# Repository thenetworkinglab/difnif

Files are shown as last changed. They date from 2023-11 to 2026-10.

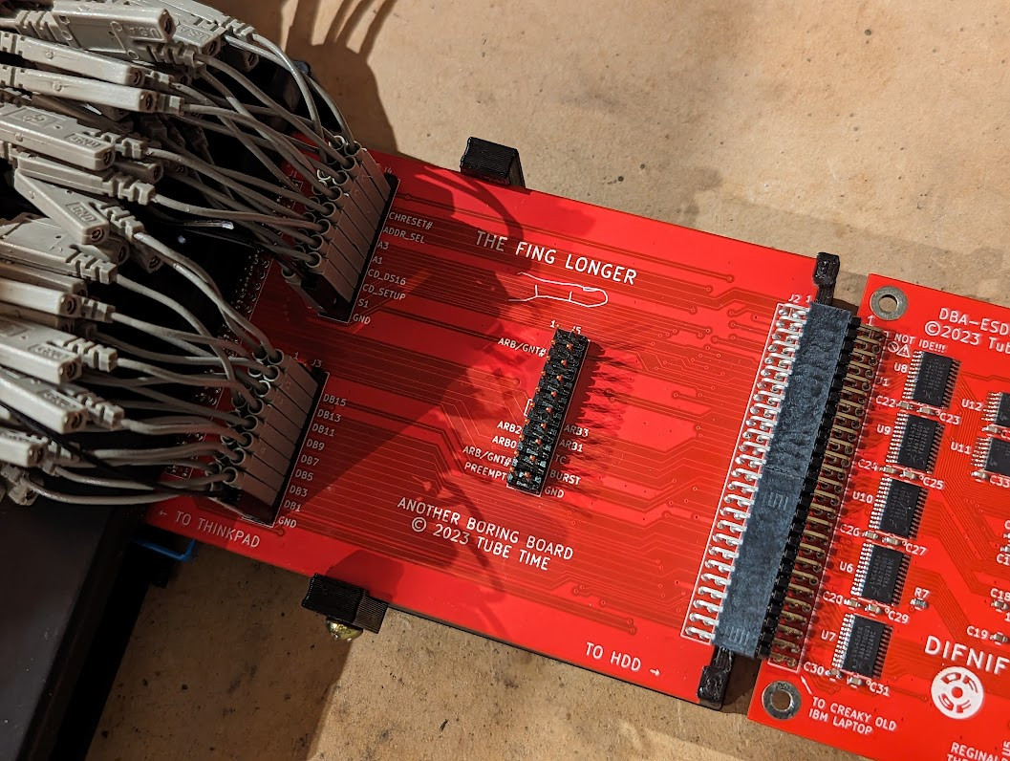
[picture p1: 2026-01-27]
photos/finglonger.jpg

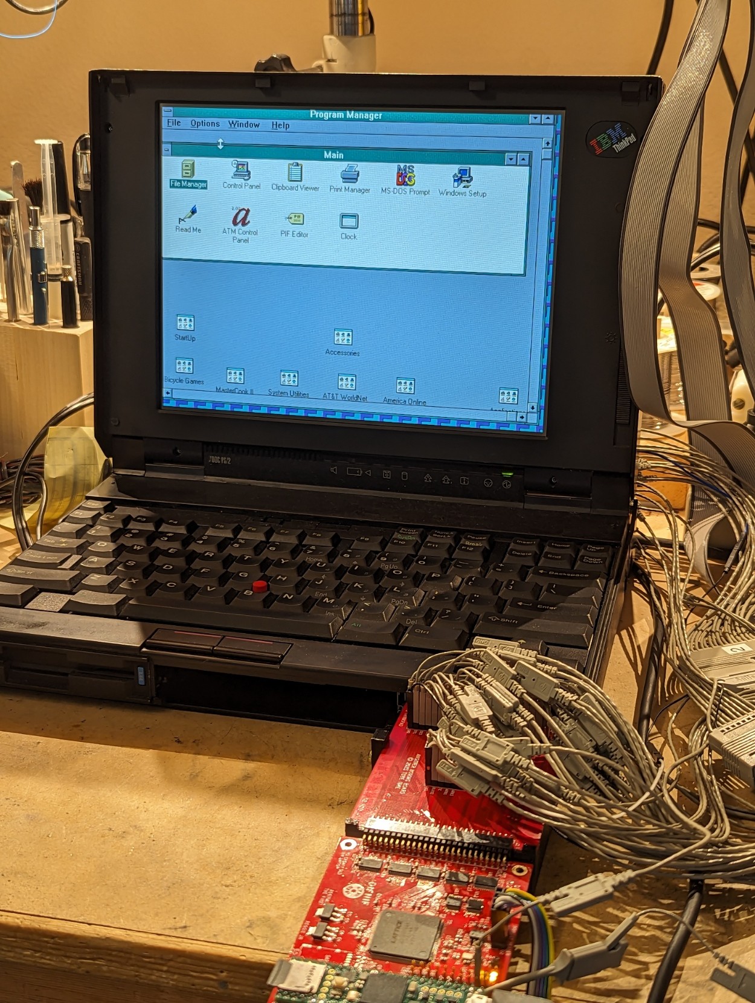
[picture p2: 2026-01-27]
photos/running.jpg

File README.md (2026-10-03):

# DifNif: DBA-ESDI Solid State Drive Emulator

DifNif is a drive emulator that replaces an IBM DBA-ESDI hard drive. 
It was designed by Eric Schlaepfer ([schlae/difnif](https://github.com/schlae/difnif)),
with the project's initial release intended to replace the hard drive in 
IBM ThinkPad 700C laptops, also including an alpha version of a PS/2 desktop 
form-factor emulator.  This fork is an attempt to complete 
the development of the 72-pin board for PS/2 desktops; the changes are 
listed in [docs/formfactor-review.md](docs/formfactor-review.md).

And before you ask: the name 'DifNif' comes from DF9F, 
the Micro Channel adapter ID that IBM's DBA-ESDI drives report.

**Status: alpha.** See "Status" below before building anything.

## Background

IBM PS/2 computers from the late 1980s and early 1990s typically used a
disk interface called DBA-ESDI (Direct Bus Attach - Enhanced
Small Device Interface). A DBA-ESDI drive has its controller integrated
with the drive electronics, and sits directly on the Micro Channel
bus, more like an IDE drive, but with its own register interface.

These drives are becoming rare because many have failed mechanically or
been damaged by leaking capacitors. MCA SCSI cards are an alternative on some
machines, but are getting expensive and difficult to find as well and 
aren't compatible with all PS/2s. Some PS/2s also need an IML (initial microcode load)
partition on their disk, and can only load it from a DBA-ESDI drive.

DifNif uses a Teensy 4.1 microcontroller and a Lattice iCE40 FPGA to implement the
DBA-ESDI interface, and stores the disk as an image file on an SD card. 

## Two boards, one design

The boards share the FPGA design (`verilog/`) and the Teensy firmware
(`difnift/`), and differ in how they connect to the computer.

| | ThinkPad board | PS/2 desktop board |
|---|---|---|
| Folder | [pcb_thinkpad](pcb_thinkpad/) | [pcb_formfactor](pcb_formfactor/) |
| Machines | ThinkPad 700C | PS/2 desktops that take a 72-pin DBA-ESDI drive, such as the 50Z, 55SX and 70 |
| Connector | 2 mm header, wired to the flex cable taken from a stock 700-series 2.5" drive | 72-pin (2 x 36) card edge, plugging straight into the drive socket |
| Carrier | [mech/df9f_carrier.STL](mech/df9f_carrier.STL) | [mech/difnif_PS2_drive_sled.STL](mech/difnif_PS2_drive_sled.STL), replacing the IBM drive sled |
| FPGA build | `make` | `make BOARD=ps2` |

There are also debugging aids:

- [pcb_finglonger](pcb_finglonger/), the "Fing Longer", for the ThinkPad board.
  It fits a 3D-printed sled ([mech/finglong.STL](mech/finglong.STL)) held by two
  clips ([mech/2finglong.STL](mech/2finglong.STL)). One acts as an extender
  that brings the connector forward, and a second as a breakout for logic
  analyzer probes on the bus lines.
- For the 72-pin board, a card in a spare Micro Channel slot gives access to
  the bus signals; Eric used a spare
  [Snark Barker MCA](https://github.com/schlae/snark-barker-mca).

## Status

- **ThinkPad board:** Eric's board works in a ThinkPad 700C,
  running Windows 3.1. The FPGA design has since been changed in this fork (see
  [docs/formfactor-review.md](docs/formfactor-review.md)), and those changes
  have **not** been tested on a ThinkPad. Eric's original files are on the
  `main` branch.
- **PS/2 desktop board, Rev P1** (Eric's): register communication didn't work
  reliably in a 50Z.
- **PS/2 desktop board, Rev P2** (this fork): fixes the problems found in a
  review of Rev P1, including a floating reset input that is the likely cause
  of the 50Z problem. The fixes have been checked in simulation against IBM's
  bus timing, but **Rev P2 has not yet been built or tested on real hardware.**
- Both boards' original design powers the 74LVC4245A level shifters the wrong
  way round, putting 5V on a supply pin rated for 4.6V at most. Rev P2 uses
  the TI SN74LVC8T245 instead, which accepts 5V on either side and fits the
  same footprint. The same swap should work on the ThinkPad board but hasn't
  been tried.
- Known bugs: writes occasionally produce a sector shifted by one byte; the
  cause hasn't been found.

[docs/formfactor-review.md](docs/formfactor-review.md) has the full list of
findings and changes, and [docs/verify-findings.md](docs/verify-findings.md)
explains how to check each one against Eric's original files and IBM's
documents.

**Data loss:** this is a hobby project with no formal testing. Keep backup
copies of all disk images.

## Building

This is an advanced project. It needs surface-mount soldering (or an
assembly service), two programmable devices to load, and probably debugging
with an oscilloscope and a logic analyzer.

### Boards

Each board folder has a `fab/` folder with Gerber and drill files. For the
Rev P2 PS/2 board, `pcb_formfactor/fab/` also has a parts list
(`DifNifFormFactor-RevP2-BOM.csv`) and a placement file
(`DifNifFormFactor-RevP2-positions.csv`) for an assembly service. The
ordering notes in [docs/formfactor-review.md](docs/formfactor-review.md)
cover board thickness, gold fingers and the bevelled edge.

The Teensy 4.1 plugs into two 24-pin female header strips (2.54 mm pitch, rows
15.24 mm apart). The SD card goes in the Teensy's own card slot.

### Teensy firmware

Load [difnift/difnift.ino](difnift/difnift.ino) with the Arduino IDE and
PJRC's Teensy board support, selecting Teensy 4.1.

For register loopback testing with DIFDIAG, comment out the two lines at the
start of `loop()` that call `esdiReset()` and `mainLoop()`. The serial monitor
then accepts the single-letter test commands listed at startup.

### FPGA

The FPGA design is built with the open-source iCE40 tools (yosys, nextpnr and
icestorm, for example from
[oss-cad-suite](https://github.com/YosysHQ/oss-cad-suite-build)). In
`verilog/`:

    make                  # ThinkPad board
    make BOARD=ps2        # PS/2 desktop board

The PS/2 build turns on the POS registers, so the card reports its `DF9F`
ID. Each build goes into its own folder, `build/thinkpad/` or `build/ps2/`.

The FPGA loads its program from an SPI flash chip on the board, which is
written through header J2 with an FTDI FT232H or FT2232H adapter and
`iceprog`:

    make prog BOARD=ps2

| J2 pin | Signal | FT232H pin |
|---|---|---|
| 1 | Flash chip select | AD4 |
| 2 | CDONE | AD6 |
| 3 | SCK | AD0 |
| 4 | CRESET | AD7 |
| 5 | Flash data out (CIPO) | AD2 |
| 6 | GND | GND |
| 7 | Flash data in (COPI) | AD1 |
| 8 | +3.3 V (board supply, leave unconnected) | |

The board must be powered while programming. The Teensy's USB connection can
power it on the bench.

The source files are:

- `difnif_top.v`: top level, wiring up the other modules.
- `mcabus.v`: the Micro Channel bus interface, with the ESDI registers, POS
  registers and DMA.
- `teensy.v`: the register interface that lets the Teensy, in its own clock
  domain, reach the ESDI mailbox registers and flags.

The self-checking bus simulation for the PS/2 board is `difnif72_t.v`, run with
`./run_sim72.sh` (needs Icarus Verilog).

## Drive images

The Teensy firmware uses a file called `disk0.img` in the root of the SD card.
Its size must be a whole number of megabytes, up to 1023 MB; for example, for
120 MB:

    dd if=/dev/zero of=disk0.img bs=1048576 count=120

Then use the machine's reference disk to create the IML and reference
partitions, and install DOS to partition and format the rest of the disk.

## DIFDIAG

[difdiag/DIFDIAG.CPP](difdiag/DIFDIAG.CPP) is a diagnostic utility for
DBA-ESDI drives that works directly with the drive hardware at a very low
level. Don't use it on drives containing data you care about, but it can help
with troubleshooting dead drives. It compiles with Borland C++ using the Large
memory model.

Menus:

- **Settings:** DMA configuration. Autoconfigure tries to get the DMA channel
  through a BIOS call, and failing that from the extended BIOS data area
  (EBDA). The channel can also be set by hand, or PIO mode chosen instead.
- **Mailbox tests:** not for real drives. With DifNif in loopback test mode
  (see "Teensy firmware"), runs millions of register cycles to look for timing
  problems.
- **Low level commands:** the lowest-level commands, which must be run in the
  sequence given by the flowcharts in the
  [ESDI spec](https://ardent-tool.com/docs/pdf/j_mcspec.pdf).
- **Drive information:** query commands; generally safe on real drives.
- **POST tests:** modelled on the drive tests run by the PS/2 BIOS.
- **Run diagnostics:** the DBA-ESDI interface's own low-level hardware
  diagnostic command.
- **Int13 tests:** destructive. Writes data through the BIOS int13 routines,
  reads it back and compares.
- **Read sector:** reads one or more sectors and shows them in hex.

## Reference documents

- [IBM DBA-ESDI reference](https://ardent-tool.com/docs/pdf/j_mcspec.pdf)
- [DBA-ESDI 72-pin connector pinout](https://ardent-tool.com/storage/DBA_ESDI.html)
- [IBM PS/2 Hardware Interface Technical Reference, Micro Channel chapter](https://ardent-tool.com/docs/pdf/ps2_50-60_techref_ch2_microchannel_architecture.pdf)

## License

Designed by Eric Schlaepfer; modified in this fork by thenetworkinglab (2026).
Licensed under the
[CERN Open Hardware Licence Version 2 - Strongly Reciprocal](https://ohwr.org/cern_ohl_s_v2.txt).

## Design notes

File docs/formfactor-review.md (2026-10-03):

# 72-pin (form factor) board: static review

Review of `pcb_formfactor/` (Rev P1) and the matching Verilog, done before
building any hardware. The goal is to get the 72-pin DifNif working in the
PS/2 55SX and 70, which use the same 2x36 DBA-ESDI edge connector as the 50Z.

Original design by Eric Schlaepfer ([schlae/difnif](https://github.com/schlae/difnif)),
CERN-OHL-S-2.0. This document and `tools/check_board.py` are additions in this fork.

## How to rerun

```
python3 tools/check_board.py
```

It exports the netlist with KiCad's `kicad-cli` and checks it against the
published connector pinout (`tools/dba_esdi_72pin.csv`), the FPGA pin file
(`verilog/difnif.pcf`) and the 74LVC4245 datasheet. It exits non-zero while
any ERROR remains, so it can gate a Rev P2 schematic.

KiCad's own ERC was also run. Almost everything it reports is noise: missing
libraries (Eric's custom libraries aren't in the repo), unused Teensy pins, and
the half-populated logic-analyzer header. It did **not** catch findings 1 or 2,
because the level-shifter pins are typed "bidirectional".

## Findings

| # | Severity | Finding | Affects |
|---|---|---|---|
| 1 | Critical | FPGA `chreset` input is floating | 72-pin only |
| 2 | High | 74LVC4245 supply rails are swapped (5 V on a 4.6 V abs-max pin) | Both boards |
| 3 | Resolved | `-ADL` not connected: not needed (IBM allows latching on `-CMD`; 17 ns hold margin) | 72-pin only |
| 4 | Medium | `-CD SFDBK` not driven (Verilog fixed; needs Rev P2 wiring) | 72-pin only |
| 5 | Low | Address decode ignores POS alternate address, answers at 0x3518-351F (fixed) | 72-pin only |
| 6 | Low | `addr_sel_l` is a `wire` assigned in an `always` block (fixed) | Verilog |
| 7 | Low | Only 6 debug signals reach the logic-analyzer header | Both boards |
| 8 | High | No key slot in the board outline | 72-pin only |
| 9 | High | Write data is captured on the falling edge of `-CMD`, where IBM guarantees 0 ns setup (fixed) | Both boards |
| 10 | High | Eric's default build hides the POS registers, including the `DF9F` adapter ID | Build setting |
| 11 | Low | Status register can change during a read cycle | Both boards |
| 12 | High | Card can bid for DMA again with a request already serviced (fixed) | Both boards |
| 13 | Note | Card relies on the planar re-arbitrating after every DMA transfer | Both boards |
| 14 | Low | The Teensy's "16-bit transfer" flag shows the width of the last bus cycle of any kind, not the last data transfer | Both boards |

### 1. FPGA `chreset` input is floating

Connector pin **B14 is `CHRESET`, active high** (IBM pinout). The schematic
names it `~{CHRESET}` and routes it through U8 channel 7 (pin 14 to pin 10) to
FPGA pin 52 (`chreset_l`), which no logic uses.

The logic uses `chreset` on FPGA pin 76. That comes from U8 pin 15
(`CHRESET_5V`), and **nothing is connected to U8 pin 15**. On the ThinkPad
board it's fed from connector pin 2.

`chreset` gates every bus access
([mcabus.v](../verilog/mcabus.v) `assign addressed = ... & ~chreset`), so
whether the card answers depends on a floating CMOS input. This matches
the README's "register communications don't work correctly".

- **Rev P1 rework:** bridge U8 pins 14 and 15 (adjacent pads). Pin 76 then
  sees the real CHRESET. No firmware change is needed.
- **Rev P2:** connect B14 to U8 pin 15 (`CHRESET_5V`). This frees U8 channel 7
  for `-ADL` (finding 3).

### 2. 74LVC4245 supply rails are swapped

All six transceivers (U6-U10, U14) are Nexperia 74LVC4245APW, per the Mouser
field. The datasheet says **pin 1 is VCC(A), the 5 V side (up to 5.5 V)**, and
**pins 23/24 are VCC(B), the 3 V side (abs max 4.6 V)**, with VCC(A) >= VCC(B).
Both boards do the opposite: pin 1 is at +3V3 and pins 23/24 are at +5V. The A
port faces the FPGA and the B port faces the bus. This was confirmed in the PCB
files as well as the schematics.

The logic still works, because each port follows its own supply. But VCC(B)
sits 0.4 V above its absolute maximum rating. The ThinkPad board works in
practice, so this probably isn't the 72-pin failure. Still, parts running
outside their ratings can behave marginally or degrade over time.

- **Fix (no layout change):** fit **TI SN74LVC8T245PW** instead. It has the same
  TSSOP-24 package and pinout: pin 1 VCCA, pin 2 DIR, pins 3-10 A, pins 14-21 B,
  pin 22 /OE, pins 23/24 VCCB. Both rails can be anywhere from 1.65 V to 5.5 V.
  DIR and /OE are referenced to VCCA (3.3 V here), which suits the FPGA driving
  DIR. The function table is the same (DIR low = B to A, high = A to B), so
  the Verilog doesn't change. This applies to both the 72-pin and ThinkPad boards.

### 3. `-ADL` not connected

On the ThinkPad connector, the system board decodes the address and hands the
drive `-ADDR_SEL` plus A0-A3. On the 72-pin connector the card gets A0-A15 raw,
and [difnif_top.v](../verilog/difnif_top.v) decodes A15-A4 without a latch. The
result is sampled on the falling edge of `-CMD`, and `-ADL` (pin A20) isn't
connected.

**Resolved: `-ADL` isn't needed.** Figure 2-34 guarantees that address and
status stay valid for at least 30 ns after `-CMD` falls (T9, T10), and note 2
explicitly allows latching on the leading edge of `-CMD` instead of `-ADL`. The
simulation passes with the address going invalid exactly at the 30 ns limit,
and the timing check below leaves 17 ns of hold margin inside the FPGA.

- **Rev P2 (optional):** A20 could still go to the spare U8 channel, freed by
  the finding 1 fix, as a debug aid. Nothing depends on it.

### 4. `-CD SFDBK` not driven

Pin B08 is `-CD SFDBK` (card selected feedback). The board leaves it open.
IBM Figure 2-34, note 1: "All slaves must drive -CD SFDBK whenever selected."
It has to come from the unlatched address decode (note 3).

- **Rev P2:** drive it through U12's spare fourth 74VHCT125 section: FPGA signal
  on the input (pin 12), /OE (pin 13) grounded, output (pin 11) to B08. That
  makes it push-pull, which is the driver type Micro Channel specifies for
  `-CD SFDBK`, the same as `-CD DS 16`. (An earlier version used the enable pin
  as an open-drain driver; it was swapped during layout, see "Rev P2 schematic
  changes".)

### 5. Address decode

`addr_sel_l <= ~(bus_a[15:4] == 12'h351)` matches 0x3510-351F. The ESDI ports
are 0x3510-3517 (primary) and 0x3518-351F (alternate, chosen by POS). As
written, the card also answers reads at the alternate address, driving `FFFF`
onto the bus and asserting `-CD DS16`. Decode A3 as well and select the base
from POS register 2 bit 1.

### 6. Verilog: `wire` assigned in `always`

`addr_sel_l` is declared `wire` in `difnif_top.v` but assigned inside
`always @(*)`. Standard Verilog rejects this and some tools refuse it. Use
`reg`, or better an `assign`, which the `-ADL` rewrite replaces anyway.

### 7. Debug visibility

The logic-analyzer header J4 only carries the six SD-card pins, which the FPGA
reuses as test outputs. For the first Rev P2 board, add test points or a second
header on `-ADL`, `-CMD`, `-S0`/`-S1`, `CHRESET`, the address decode, and
`-CD DS16`.

### 8. No key slot in the board outline

The IBM drive's edge connector has a key slot between pins 2 and 3, visible
on both rows of a WD-3158. Eric's `BUS_DBA_ESDI` footprint draws the slot, at
the right position (1.27 mm past pin 2), but only on the `Dwgs.User` layer. The
board outline and the fab Gerber (`DifNif-Edge_Cuts.gbr` in the RevP1 zip) are
a plain 98.8 x 93.0 mm rectangle with no slot. The 55SX's cable-end socket has a
key ridge, so Rev P1 won't go into a 55SX without a slot cut by hand. The Model
70's riser socket has no key, so Rev P1 fits there as it is.

Measured on a WD-3158: the slot is **11.7 mm deep** and about **1.0 mm wide**,
cut right up against the edges of fingers 2 and 3 with no copper margin. The
IBM fingers are about 1.5 mm wide, the same as Eric's 1.524 mm, so the slot
fills the roughly 1.0 mm gap between them. The key ridge in the 55SX
flat-flex cable socket measures about **0.7 mm** thick, and the cable is keyed
at both ends. The Model 70's riser socket is **not** keyed (checked on a real
machine): its chassis makes it practically impossible to fit a drive upside
down, whereas the 55SX's loose flex cable could be plugged in either way with
the machine apart. The slot is harmless in the Model 70.

- **Rev P2 (done):** a slot 1.0 mm wide and **8.7 mm** deep, centred between
  pins 2 and 3, with a rounded end, and fingers a2/a3/b2/b3 narrowed to 1.0 mm
  (centred) for 0.27 mm of copper-to-edge clearance. The slot doesn't need
  IBM's 11.7 mm: the drive goes only 7.5-7.8 mm into the 55SX cable socket
  (measured by fitting the socket on the WD-3158), so the key ridge can't
  reach further than that. 8.7 mm is the deepest slot that clears the existing
  traces fanning out from fingers A1/A2/B1/B2 (8.8 mm touches `A13`), leaving
  about 1 mm of margin. Check the board house's minimum routed slot width
  (often 1.0 mm) and copper-to-edge clearance.
- **Rev P1:** could be keyed by hand. A fine jeweller's saw (about 0.8 mm kerf)
  cutting down the 1.0 mm gap between fingers 2 and 3, about 8.5 mm deep,
  would clear the 0.7 mm ridge.

### 9. Write data captured at the falling edge of `-CMD`

[mcabus.v](../verilog/mcabus.v) stores host writes (CIFR, ATN, BCR, DREG and
POS registers) on `negedge cmd_l`. IBM Figure 2-34 only guarantees write data
**0 ns** before `-CMD` falls (T17), and 30 ns after `-CMD` *rises* (T18). With
data arriving at the limit, any data line whose path through the level shifter
is slower than the `-CMD` line's gets captured before the new value arrives.

The simulation reproduces this: at IBM's timing limits, host writes fail on 7
of 8 randomly chosen sets of level-shifter delays, on all three machines. Reads
are unaffected. Eric's measurements on his 50Z show about 50 ns of write setup,
which is why typical timing passes. How much setup the 55SX and Model 70 really
give is unknown.

This affects both boards and could contribute to the README's "sector written
is shifted by one byte" bug, though that isn't proven.

- **Verilog fix:** latch the address and status on the falling edge (as now),
  but store the write data on the rising edge of `-CMD`, where it is guaranteed
  valid for another 30 ns. The Teensy-facing "register full" flags have to move
  with it, so the Teensy never sees a flag before its data.

### 10. POS registers hidden in Eric's default build

`mcabus.v` defines `MCA_NO_POS` ("POS bypass", added January 2026). The card
is then always enabled but never answers setup cycles, so the host can't read
the `DF9F` adapter ID. The ThinkPad presumably doesn't need it. On the 72-pin
connector the drive has its own `-CD SETUP` line, and the 50Z/55SX/70 BIOS
probably reads the ID to find the drive. The define can now be overridden with
`-DMCA_USE_POS` without changing the default, and the simulation passes the POS
tests in that mode. Build the 72-pin board's FPGA program with
`make BOARD=ps2` in `verilog/`, which sets it (plain `make` builds the
ThinkPad version, POS bypassed, into a separate folder). Program it with
`make prog BOARD=ps2`.

### 11. Status register can change during a read

The basic status register is read live, not snapshotted when the cycle starts.
If a flag changes while `-CMD` is low (for example the Teensy emptying CIFR),
the data on the bus changes mid-cycle. IBM wants read data valid within 60 ns
of `-CMD` falling (T20). Each bit is either the old or the new value, so this is
usually harmless, but a snapshot at the start of the cycle would be cleaner.
The simulation reports these as SPEC notes, not failures.

### 12. DMA request dropped too late

The card asks for DMA while its data-register request flag (`flag_treq`) is
set. A DMA transfer clears that flag through the 50 MHz synchronizer, 40-60 ns
after the transfer's `-CMD` rises. IBM allows the next arbitration cycle to
start 30 ns after the end of a transfer (Figure 2-46, T41). The card decides
whether to compete when `ARB/-GNT` rises, so on a planar that re-arbitrates
that quickly, it competes again with a request that has already been serviced,
wins, and receives (or supplies) a word the Teensy isn't ready for.

The simulation reproduces it at IBM's limits: a whole 16-word DMA transfer went
through on a single request. At typical timing (arbitration 100 ns after the
transfer) it doesn't happen. How fast real 55SX and Model 70 planars
re-arbitrate is unknown. This may also be what Eric's "fix rare dma glitch"
commit was working around.

**Fixed:** `dma_requested` is now also gated by `treq_pending`, which rises the
moment a DREG or DMA cycle's `-CMD` rises and falls one clock after `flag_treq`
clears, so the request never glitches back on.

### 13. Dependence on re-arbitration after DMA

After winning arbitration, the card stays "DMA selected" for any I/O cycle
until `ARB/-GNT` next goes high (`dma_cycle` only updates on that edge). If a
planar handed the bus back to the CPU without an arbitration cycle, the card
would treat the CPU's next I/O cycles as DMA transfers. IBM's timing (T41) and
Eric's note about the real 50Z in `mcabus_t.v` indicate the planar does
re-arbitrate after each transfer, and the simulation models it that way. This
is worth confirming with a logic analyzer on real hardware.

### 14. "16-bit transfer" flag tracks every bus cycle

The FPGA gives the Teensy a flag (`t_treq_16`, flag register bit 9,
`FLAG_TRANSFER_16` in `difnift.ino`) meant to say whether the last data
register (DREG) transfer was 8 or 16 bits wide. [mcabus.v](../verilog/mcabus.v)
sets it from `-SBHE`, which is latched on the falling edge of `-CMD` in
**every** bus cycle, including other devices' cycles and the host's own status
polls. In simulation it read 0 after every transfer, even 16-bit ones, because
the host's 8-bit reads of the status register came in between.

The firmware never reads the flag; it treats every transfer as 16 bits. That's
fine as long as the host always moves sector data 16 bits at a time, which it
should, since the card asserts `-CD DS 16` for DREG and DMA cycles. If 8-bit
transfers ever need supporting, the FPGA should latch `-SBHE` only on DREG and
DMA cycles, and the firmware should check the flag.

### The "shifted by one byte" write bug (open)

Eric's README reports occasional sector writes that come out shifted by one
byte. The cause isn't known. Checked so far:

- **8-bit transfers: ruled out as the cause.** A temporary simulation had the
  host write known bytes to DREG with 8-bit cycles, while a Teensy model
  stored two bytes per transfer as `difnift.ino` does. The host sent
  `11 22 33 44`; the Teensy stored `11 88 22 88 33 88 44 88` (the `88` left
  over from an earlier 16-bit write). An 8-bit transfer interleaves junk bytes
  and doubles the length; it doesn't shift the data by one byte.
- **The Teensy's read-then-write of the flag register: harmless.** `setFlag`
  and `clearFlag` read the flags and write them back. In
  [teensy.v](../verilog/teensy.v) the only stored bits are the Teensy's own
  (command in progress and clear all); "set transfer request" (bit 5) reads
  back as 0 and "clear busy" (bit 7) as 1, so writing back what was read never
  triggers either.
- **Finding 12, stale DMA requests: no data corruption seen.** With the fix
  undone, the card wins the bus once more after its last transfer and then
  disturbs the host's next I/O cycles, but in simulation every sector word
  still reached the Teensy intact.
- **Finding 9, write data timing:** would corrupt individual words rather than
  shift them, and Eric's 50Z gives about 50 ns of setup, so it probably isn't
  the cause either.

To try on real hardware:

- **Turn off the USB serial output.** The firmware prints for every command
  and sector, and prints the first word of each sector written. The data
  handshake waits for the Teensy, so slowness alone shouldn't lose data, but
  the extra time changes the timing and could expose a race or a host timeout.
  Comparing runs with and without the prints is a cheap test.
- **Look at a damaged sector.** Whether the shift is really one byte or one
  16-bit word points in different directions: a word shift means a transfer
  lost or repeated, a byte shift needs some byte-wide event.
- **Reproduce it with DIFDIAG's Int13 test** (writes, reads back and compares)
  while capturing the bus with a logic analyzer.

## Mechanical

Confirmed against a real drive (IBM FRU 6128291, model WD-3158, 120 MB):

| Item | WD-3158 | Rev P1 board | Match |
|---|---|---|---|
| Connector tab width | 93 mm (measured) | 93.0 mm (Edge.Cuts) | Yes |
| Finger pitch | 2.54 mm, 36 per side | 2.54 mm, 36 per side | Yes |
| Finger length | about 7 mm (from photo); the gold stops about 1 mm short of the edge | 6.86 mm, running to the edge (Rev P2: starting 1.15 mm in) | Yes |
| Row A side | top of PCB, facing the drive casing | F.Cu, the component side | Yes |
| Pin 1 end | A1 on the right, looking down with fingers pointing away | a1 on the right, same view | Yes |
| Board thickness | 1.6 mm (measured across fingers) | 1.6 mm | Yes |
| Finger width | about 1.5 mm | 1.524 mm | Yes |
| Key slot | between pins 2 and 3 | none | **No** (finding 8) |

Where the connector sits on the drive:

- The finger tips stick out **23.8 mm** past the end of the drive's black
  aluminium frame.
- The drive PCB is recessed about **1 mm** into the frame: the bottom edge of
  the frame sticks out about 1 mm further than the PCB's underside.
- The frame has recesses along its sides for the screw holes, and the drive PCB
  has matching cutouts plus a few others.

### Approach

We are **not** trying to make a board shaped like the drive's own PCB that
bolts to a drive chassis. The DifNif stays a small board (Rev P1 is 93 x 98.8 mm)
that plugs into the machine's connector. A **3D-printed carrier** for each
machine then mounts in the drive bay the way the IBM drive does and holds the
board so its connector lands where the drive's did. Eric's
`mech/difnif_PS2_drive_sled.STL` already follows this pattern: it's a
102 x 155 x 18.5 mm open frame with side rails that replaces the IBM drive
sled, and its four 2.5 mm holes (85 x 77 mm apart) match the board's four
2.7 mm mounting holes, for M2.5 screws. Rev P2 keeps those holes where they
were, so the plan is to print Eric's sled and test-fit it in a 55SX and a
Model 70 before designing anything new.

Carriers are cheap to print and reprint, so fitting them can be done by trial
without touching the PCB. The PCB only has to get the edge connector right
(width, pitch, key, thickness) and keep its mounting holes where the carrier
expects them.

To check during the test fit, per machine:

- How the drive is held in the bay (rails, screws, tray) and the positions of
  those mounting points
- Clearance above and below the drive, including the 55SX cable yoke
- Whether the tall parts (the socketed Teensy 4.1) and the microSD slot fit and
  stay reachable

## Verilog fixes

Findings 4, 5, 6 and 9 are fixed in `verilog/`.

**Write capture (finding 9), [mcabus.v](../verilog/mcabus.v):**

- Address, status, byte enable, "addressed" and "DMA selected" are latched on
  the falling edge of `-CMD`, as before.
- Write data (CIFR, ATN, BCR, DREG, POS 2-4, and DMA writes to DREG) is stored
  on the rising edge of `-CMD`, using those latched values.
- The host-side mailbox events (ATN written, CIFR written, ISR read, SIFR read,
  DREG accessed) flip a toggle on the rising edge of `-CMD`. The 50 MHz domain
  detects each flip through a two-stage synchronizer. Each host cycle produces
  exactly one event, and the Teensy never sees a "full" flag before its data.
- Side effect: ISR, SIFR and DREG flags now clear as soon as the host's read
  ends, instead of partway into the host's *next* bus cycle. The old behaviour
  meant the last word of a transfer stayed "requested" until the host did
  something else.

**Address decode (finding 5), [difnif_top.v](../verilog/difnif_top.v):** the
72-pin decode compares A15-A3 against 3510 or, when POS 2 bit 1 is set, 3518.
Registers are selected by A2-A0, so both bases work. A disabled card (POS 2
bit 0 clear) now answers only setup cycles, including for `-CD DS 16`. The
ThinkPad path (`fulladdr_l` high) is unchanged.

**`-CD SFDBK` (finding 4):** new output `cd_sfdbk_l`, asserted from the
unlatched decode whenever the card is selected by the processor or DMA, but not
by `-CD SETUP` (IBM notes 1 and 3). It's assigned to FPGA pin 134 in
[difnif.pcf](../verilog/difnif.pcf), which is unconnected on Rev P1. Rev P2
needs it wired to U12 pin 12 (input of the spare 74VHCT125 section, /OE pin 13
grounded) with the output (pin 11) to J1 B08, push-pull. `tools/check_board.py`
reports it until then.

**Results:** `run_sim72.sh` passes every test on the bridged Rev P1 and Rev P2
models, on all three machines, at typical timing and at IBM's limits for all 8
delay sets, with POS enabled. In POS bypass mode only the two POS tests fail, by
design. Rev P2 also passes the `-CD SFDBK` timing check (valid within 60 ns of
the address, T14). The FPGA build uses 438 of 7680 logic cells, and the
`-CMD`-clocked logic reports about 88 MHz, far above what a 90 ns `-CMD` pulse
needs.

Because POS writes are now stored as `-CMD` rises, a new POS setting takes
effect when the POS write cycle ends. A host cycle overlapping that write still
sees the old setting. That's normal for Micro Channel cards.

**DMA (finding 12):** see finding 12. Also, a DMA I/O cycle can no longer
trigger mailbox flags, whatever address the DMA controller puts on the bus
(`la_io` excludes DMA cycles).

**Not yet verified:**

- **The ThinkPad 700C.** Finding 9's fix changes the ThinkPad build too. It's
  per IBM's timing rules, but nobody has run it on a 700C.

## Timing check

The simulations treat the FPGA as having no internal delay.
[tools/timing_budget.py](../tools/timing_budget.py) closes that gap. It builds
the design with yosys and nextpnr, takes nextpnr's worst delay for each class
of path, adds the clock-network delay from nextpnr's SDF file, allowances for
the FPGA's pad buffers, and worst-case delays of the board's other chips from
their datasheets, then compares the total with IBM's limits:

| IBM | Requirement | Limit | Budget | Margin |
|---|---|---|---|---|
| T13 | `-CD DS 16` from address | 55 max | 30.6 | 24.4 |
| T14 | `-CD SFDBK` from address | 60 max | 30.6 | 29.4 |
| T2/T15 | address/status setup at `-CMD` falling | 0 min | 39.8 | 39.8 |
| T9/T10 | address/status hold after `-CMD` falling | 2.4 min | 19.8 | 17.4 |
| T16/T17 | write data setup at `-CMD` rising | 0 min | 78.0 | 78.0 |
| T18 | write data hold after `-CMD` rising | 2.4 min | 19.8 | 17.4 |
| T16 | falling-edge latches to rising-edge logic | 0 min | 84.3 | 84.3 |
| T20 | read data valid from `-CMD` falling | 60 max | 35.6 | 24.4 |
| T22 | read data released after `-CMD` rising | 40 max | 30.6 | 9.4 |
| T42 | `-PREEMPT` released after `ARB/-GNT` low | 50 max | 22.2 | 27.8 |
| T45 | ARB drivers on after `ARB/-GNT` high | 50 max | 25.8 | 24.2 |
| T45A/T47 | ARB driver follows another ARB line | 50 max | 27.6 | 22.4 |
| T41 | DMA request dropped before next `ARB/-GNT` (finding 12) | 0 min | 17.8 | 17.8 |

All values in ns, default build; the `--pos` build is within 1 ns of these.
Every requirement passes. The tightest is T22 (the card letting go of the data
bus after a read) at 9.4 ns, and that's with the pessimistic assumptions below.

How pessimistic the numbers are:

- **FPGA:** each row uses the worst path nextpnr found in its whole class. For
  example, every pin-to-pin row uses 10.6 ns, the Teensy address-to-data path,
  not the faster address decoder paths. nextpnr doesn't model the pad buffers,
  so 1.5 ns is added at each pad. That matches Lattice's worst-case 7.3 ns for
  a pin-to-LUT-to-pin path on HX parts (85 °C, minimum core voltage).
- **Board:** level shifters use 7 ns worst case in either direction (SN74LVC8T245
  at 3.3 V/5 V is 6.0 and 4.4), 15 ns for the data transceivers to turn around,
  and 10 ns for the 74VHCT125 (from TI's equivalent SN74AHCT125 at 50 pF). The
  74LCX07 uses 7 ns, double TI's SN74LVC07A figure, because I couldn't get ST's
  datasheet.
- **Hold checks** assume the data path inside the FPGA takes 0 ns and the clock
  path takes its maximum.
- **Not covered:** Rev P1's 74LVC4245As have their supplies swapped (finding 2),
  so their delays aren't specified at all. PCB trace delays (about 0.2 ns) are
  left out. The rise time of open-drain lines depends on the planar's pull-ups.

Rerun it after any Verilog change, since placement moves paths around:
`python3 tools/timing_budget.py` and `python3 tools/timing_budget.py --pos`.

## Rev P2 schematic changes

Made directly in `pcb_formfactor/DifNif.kicad_sch` and `DifNifBus.kicad_sch`
(still KiCad 6 format; KiCad 9 converts them when saved). After the changes,
`tools/check_board.py` reports 0 errors (it was 9), and KiCad's ERC shows 12
fewer problems and no new ones.

| Finding | Change |
|---|---|
| 1 | Net at J1 B14 renamed `~{CHRESET}_5V` -> `CHRESET_5V`, which joins B14 to U8 pins 14 **and** 15. The FPGA's `chreset` (pin 76) now sees the real CHRESET; pin 52 gets it too, unused. |
| 2 | U6-U10, U14: value `74LVC8T245`, Mouser `595-SN74LVC8T245PWR` (was 74LVC4245 / 771-74LVC4245APW-T). Same TSSOP-24 footprint and pinout; the existing supply wiring (pin 1 = 3.3 V, pins 23/24 = 5 V) is correct for this part. The schematic symbol is renamed `74LVC8T245`, with TI's pin names (A1-A8 on pins 3-10, B1-B8 on pins 21-14; Nexperia calls the same pins A0-A7/B0-B7), TI's datasheet link, /OE typed as an input, and the DIR notes confirmed against TI's function table. Netlist connectivity is identical before and after the rename. |
| 4 | U12 section 4 is the `-CD SFDBK` driver, push-pull: pin 12 (input) connects to new hierarchical net `~{CD_SFDBK}` -> sheet pin -> FPGA pin 134 (and J4 pin 11); pin 13 (/OE) stays grounded; pin 11 (output) connects to J1 B08 via `~{CD_SFDBK}_5V`. No-connect flags removed from U12 pin 11 and J1 B08. First done with the signal on pin 13 (open-drain); swapped during layout because routing to pin 13 cut pin 12's ground off from the top pour, and push-pull is what IBM specifies anyway. |
| 7 | Logic-analyzer header J4: its 11 unused data pins now carry FPGA-side bus signals (below). No new parts. |

J4 (HP logic analyzer pod) assignments:

| J4 pin | Pod bit | Signal | | J4 pin | Pod bit | Signal |
|---|---|---|---|---|---|---|
| 4 | D15 | `-CMD` | | 5 | D14 | `-S0` |
| 6 | D13 | `-S1` | | 7 | D12 | `M/-IO` |
| 8 | D11 | `-CD SETUP` | | 9 | D10 | `CHRESET` |
| 10 | D9 | `-CD DS 16` | | 11 | D8 | `-CD SFDBK` |
| 12 | D7 | `DATA_DIR` | | 13 | D6 | `ARB/-GNT` |
| 14 | D5 | `-PREEMPT` | | 3, 15-19 | CLK, D4-D0 | SD-card pins, as before |

Not changed in the schematic:

- **`-ADL`** (finding 3): not needed, so A20 stays unconnected.
- **Pull-ups on the FPGA-driven buffer inputs.** Eric's `-IRQ14` and `-CHRDY`
  are driven through buffer enables, and `-CD DS 16` and `-CD SFDBK` through
  buffer inputs, straight from the FPGA. Before the FPGA has loaded its
  configuration, those pins only have whatever pull-up the iCE40 applies during
  configuration. If that isn't guaranteed, a 10 k pull-up to 3.3 V on each
  would keep them quiet at power-up. Worth checking in Lattice's configuration
  documentation.
- **The ThinkPad board** has the same swapped-supply 74LVC4245s (finding 2). The
  same part swap would fix it; not done here.

### Layout work (in KiCad's PCB editor)

1. **Update PCB from Schematic** (Tools menu, or F8). New connections to route:
   J1 B14 to U8 pin 15; J1 B08 to U12 pin 11; U12 pin 12 to FPGA pin 134
   (routed via J4 pin 11, whose through-hole pad doubles as a via); and J4 pins
   4-14 to their signals. Route the U12 pin 12 stub on the top layer away from
   pin 13, so pin 13 keeps its ground connection to the pour.
2. ~~**Key slot** (finding 8).~~ Done: Edge.Cuts slot x = 91.2 to 99.9 mm
   (8.7 mm deep, rounded end), y = 43.36 to 44.36 mm; pads a2, a3, b2 and b3
   narrowed to 1.0 mm, centred. DRC shows nothing new, and the ground pour is
   intact.
3. ~~Silkscreen.~~ Done: front reads "REV P2 / 09/26"; the back credits add
   "thenetworkinglab: Rev P2 changes".
4. **Debug header J4:** 10 of the 11 new debug connections are left unrouted
   for now (only `-CD SFDBK` on pin 11 is routed). DRC lists them as
   unconnected; the silkscreen still marks those pins "n".

### Fab files

`pcb_formfactor/fab/DifNifFormFactor-RevP2.zip`, the same 11 files as Eric's
RevP1 zip (9 Gerber layers with X2 attributes, separate PTH/NPTH Excellon
drill files in mm), exported with KiCad 9 after refilling the ground pours.

When ordering:

- **1.6 mm** FR-4, 2 layers.
- **Gold fingers** on the edge connector (hard gold if the board house offers
  it; ENIG is a cheaper second best for a board that won't be plugged in often).
- **Bevelled edge** on the connector side, typically 30-45 degrees.
- The fingers start **1.15 mm in from the edge**, so the bevel doesn't grind
  into the gold. PCBWay asked for this clearance for a 30 degree bevel leaving
  0.5 mm at the tip, and is trimming the ordered boards to match; the files now
  show it. The IBM drive's own fingers stop about 1 mm short of the edge.
- The key slot is a **1.0 mm routed slot** with 0.27 mm between it and the
  nearest finger copper. Check both against the board house's minimum slot
  width and copper-to-edge clearance.
- Look the files over in a Gerber viewer first (KiCad's GerbView works): the
  slot on Edge.Cuts, the narrowed fingers 2 and 3, the gap between the finger
  tips and the edge, and the silkscreen text.

## Suggested next steps

1. ~~Add DMA transfers to `difnif72_t.v`.~~ Done.
2. ~~Timing check of the FPGA's internal delays.~~ Done: see "Timing check".
3. ~~Rev P2 schematic changes and layout.~~ Done: see "Rev P2 schematic
   changes". Boards ordered (PCBWay, assembled).
4. Print Eric's `mech/difnif_PS2_drive_sled.STL` and test-fit it in a 55SX and
   a Model 70.
5. Bring-up: program the FPGA (`make BOARD=ps2`, then `make prog BOARD=ps2`),
   then test in a machine.

## Toolchain status

oss-cad-suite 2026-09-23 build (Yosys 0.69, nextpnr 0.11.1, Icarus Verilog 14
devel), installed in `/opt/oss-cad-suite`.

- **FPGA build (`make` in `verilog/`)** works unchanged. The nextpnr and icetime
  timing estimate is about 80 MHz worst case, against the 50 MHz internal clock.
  The Makefile now takes `BOARD=thinkpad` (the default) or `BOARD=ps2`
  (the 72-pin board, POS registers on) and builds each into `build/<board>/`.
- **Simulation (`verilog/sim.sh`)** failed with Icarus 14: `mcabus.v` used six
  signals before declaring them, which newer Icarus rejects. The declarations
  were moved to the top of the module. A Yosys formal equivalence check
  (`equiv_make`/`equiv_induct`) proved the reordered module identical to the
  original: 297 of 297 equivalence points proven. The testbench now runs to
  completion and writes `sim.vcd`.
- The testbench has no self-checks yet: it drives bus cycles and dumps
  waveforms but never compares results. Adding checks is part of the next step.

## Simulation

[verilog/difnif72_t.v](../verilog/difnif72_t.v) is a self-checking testbench
around the unmodified FPGA design. It models:

- **the host**, following IBM's Figure 2-34 timing either at its limits or at
  typical values Eric measured on a 50Z, with 300, 250 and 200 ns cycles
  (50Z, 55SX, Model 70). Address and status really do go invalid (`x`) once
  their hold times expire, and unused data lanes carry garbage.
- **the Rev P1 board**, with each level-shifter channel given its own delay in
  the datasheet's 1.0-7.0 ns range (varied by `SEED`), and the floating FPGA
  reset input (as built) or the U8 14/15 bridge.
- **the Teensy**, using the same register timing as `difnift.ino` and the same
  mailbox handshakes as DIFDIAG, checking every value.
- **the planar's central arbiter and DMA controller**: `-PREEMPT`, a 300 ns
  arbitration cycle with the ARB bus resolved by open-collector drivers, the
  winner releasing `-PREEMPT` within 50 ns (T42), two-cycle DMA transfers
  (memory then I/O for sector writes, I/O then memory for sector reads) with
  `-TC` on the last one, and a new arbitration cycle 30 ns (limit) or 100 ns
  (typical) after every transfer. A second DMA device at a higher or lower
  priority competes for the bus, and the CPU does unrelated I/O in between; the
  card must never answer those cycles.

Run `verilog/run_sim72.sh` (about 50 seconds for 162 simulations;
`run_sim72.sh quick` runs one delay set). Results **before** the Verilog fixes:

| Board | POS | Timing | Result (all three machines) |
|---|---|---|---|
| As built | either | either | Every register test fails (finding 1) |
| Bridged | bypass | typical | Mailboxes pass; POS tests fail (finding 10); 3518 answered (finding 5) |
| Bridged | enabled | typical | All pass except 3518 answered (finding 5) |
| Bridged | either | IBM limits | Host writes fail on 7 of 8 delay sets (finding 9); reads pass |

**After** the fixes, the bridged board and Rev P2 pass everything with POS
enabled, including DMA in both directions with competing devices. See
"Verilog fixes" above.

The simulated FPGA has no internal delays (it's RTL simulation), and a floating
input is modelled as "unknown", so on real hardware finding 1 would show up as
intermittent failures rather than constant ones. That matches "some sort of
timing error".

The existing [verilog/sim.sh](../verilog/sim.sh) (Eric's DMA-focused testbench)
still runs as before.

To make `difnif_top.v` and `teensy.v` compile in Icarus, two trailing commas
were removed and two `wire`s assigned in `always` blocks became `reg`s
(finding 6). Yosys proved the result logically identical to the original:
845 of 845 equivalence points.

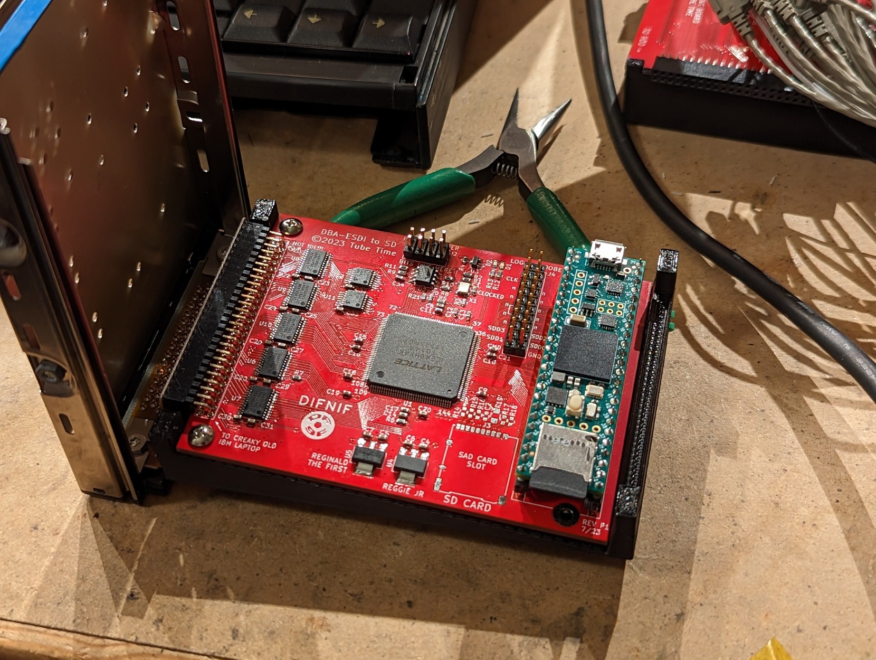
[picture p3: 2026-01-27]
photos/difnif.jpg

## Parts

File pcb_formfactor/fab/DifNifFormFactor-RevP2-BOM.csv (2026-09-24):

Item | Qty | Designators | Manufacturer | Manufacturer Part Number | Description | Value | Footprint | Type | Fitted by | Mouser | Notes
1 | 13 | C1 C2 C9 C10 C11 C12 C13 C15 C16 C17 C18 C19 C34 | TDK | CGA3E1X7R1C105AC | Capacitor 1u 0603 | 1u | CAPC1608X100 | SMD | Assembler | 810-CGA3E1X7R1C105AC
2 | 14 | C3 C22 C23 C24 C25 C26 C27 C28 C29 C30 C31 C32 C33 C35 | Samsung Electro-Mechanics | CL10B104KB8NNNC | Capacitor 0.1uF 0603 | 0.1uF | CAPC1608X100 | SMD | Assembler |  | Any 0.1 uF X7R 0603 rated 16 V or more is fine
3 | 8 | C4 C5 C6 C7 C8 C14 C20 C21 | Samsung Electro-Mechanics | CL10A475KP8NNNC | Capacitor 4.7u 0603 | 4.7u | CAPC1608X100 | SMD | Assembler | 187-CL10A475KP8NNNC
4 | 2 | D1 D2 |  |  | LED, 0603 | LED | LEDM1608X50 | SMD | Assembler |  | Any 0603 LED (e.g. green); 470 ohm from 3.3 V
5 | 1 | D3 | Nexperia | PMEG10010ELRX | Schottky diode 1 A 100 V, SOD-123F | PMEG10010ELR | SOD3716X117 | SMD | Assembler | 771-PMEG10010ELRX
6 | 1 | J3 | Hirose | DM3AT-SF-PEJM5(40) | microSD socket | SDCARD_DM3AT-SF-PEJM5 | microSD_HC_Hirose_DM3AT-SF-PEJM5 | SMD | Assembler | 798-DM3AT-SF-PEJM540 | Check: Mouser code ends in 40, Hirose's packaging variant
7 | 6 | R1 R4 R8 R9 R10 R11 | Yageo | RC0603FR-0710KL | Resistor 10K 0603 | 10K | RESC1608X55 | SMD | Assembler | 603-RC0603FR-0710KL
8 | 6 | R2 R3 R20 R21 R22 R23 | Yageo | RC0603FR-0710RL | Resistor 10 0603 | 10 | RESC1608X55 | SMD | Assembler | 603-RC0603FR-0710RL
9 | 2 | R5 R6 | Yageo | RC0603FR-07100RL | Resistor 100 0603 | 100 | RESC1608X55 | SMD | Assembler | 603-RC0603FR-07100RL
10 | 1 | R7 | Yageo | RC0603FR-071KL | Resistor 1K 0603 | 1K | RESC1608X55 | SMD | Assembler | 603-RC0603FR-071KL
11 | 2 | R12 R13 | Yageo | RC0603FR-07470RL | Resistor 470 0603 | 470 | RESC1608X55 | SMD | Assembler | 603-RC0603FR-07470RL
12 | 5 | R14 R15 R16 R17 R18 | Yageo | RC0603FR-0747KL | Resistor 47K 0603 | 47K | RESC1608X55 | SMD | Assembler | 603-RC0603FR-0747KL
13 | 1 | R19 | Yageo | RC0805FR-070RL | Resistor 0 0805 | 0 | RESC2012X55 | SMD | Assembler | 603-RC0805FR-070RL
14 | 1 | U1 | Lattice Semiconductor | ICE40HX4K-TQ144 | FPGA, iCE40 HX4K, TQFP-144 | ICE40HX4K-TQ144 | TSQFP50P2200X2200X160-144 | SMD | Assembler | 842-ICE40HX4K-TQ144
15 | 1 | U2 | Microchip Technology | SST26VF080A-104I/SN | SPI flash 8 Mbit, SOIC-8 (FPGA configuration) | SST26VF080A-104I/SN | SOP127P620X175-8 | SMD | Assembler | 579-26VF080A-104I/SN
16 | 1 | U3 | Diodes Incorporated | APX803S00-29SA-7 | Reset supervisor 2.93 V, SOT-23 | APX803S00-29SA-7 | SOT95P230X117-3 | SMD | Assembler | 621-APX803S00-29SA-7
17 | 1 | U4 | Diodes Incorporated | AP2114HA-3.3TRG1 | LDO 3.3 V, SOT-223 | AP2114HA-3.3 | SOT230P700X170-3 | SMD | Assembler | 621-AP2114HA-3.3TRG1
18 | 1 | U5 | Diodes Incorporated | AP2114HA-1.2TRG1 | LDO 1.2 V, SOT-223 | AP2114HA-1.2 | SOT230P700X170-3 | SMD | Assembler | 621-AP2114HA-1.2TRG1
19 | 6 | U6 U7 U8 U9 U10 U14 | Texas Instruments | SN74LVC8T245PWR | Dual-supply octal transceiver, TSSOP-24 | 74LVC8T245 | TSOP65P640X120-24 | SMD | Assembler | 595-SN74LVC8T245PWR
20 | 1 | U11 | Toshiba | 74LCX07FT | Hex open-drain buffer, TSSOP-14 | 74LCX07 | TSOP65P640X110-14 | SMD | Assembler | 757-74LCX07FTAE | Check: Mouser code adds a packaging suffix (AE)
21 | 1 | U12 | Toshiba | 74VHCT125AFT | Quad tri-state buffer, TSSOP-14 | 74VHCT125 | TSOP65P640X110-14 | SMD | Assembler | 757-74VHCT125AFT
22 | 1 | X1 | ECS Inc. | ECS-2333-100-BN-TR | Oscillator 10 MHz | ASE-xxxMHz | XTAL320X250X120-4 | SMD | Assembler | 520-ECS-2333-100-BNT | Check: 10 MHz 3.3 V oscillator, 3.2 x 2.5 mm; Mouser code drops the -TR punctuation
23 | 1 | J2 |  |  | 2x4 pin header, 2.54 mm | PROG | PinHeader_2x04_P2.54mm_Vertical | THT | Customer |  | FPGA flash programming header
24 | 1 | J4 |  |  | 2x10 pin header, 2.54 mm | HPLA_PORT | PinHeader_2x10_P2.54mm_Vertical | THT | Customer |  | Logic analyzer header (HP pod)
25 | 1 | U13 |  |  | 2x 1x24 female socket strips, 2.54 mm, rows 15.24 mm apart | Teensy4_1 | DIP-48_W15.24mm_Socket | THT | Customer |  | Socket for the Teensy 4.1 (Teensy fitted separately)

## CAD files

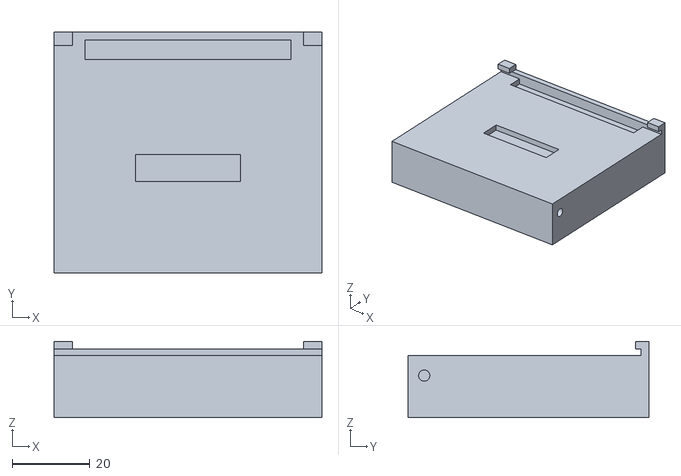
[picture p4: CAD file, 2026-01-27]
mech/la_fl.STL
69.0 x 62.0 x 19.6

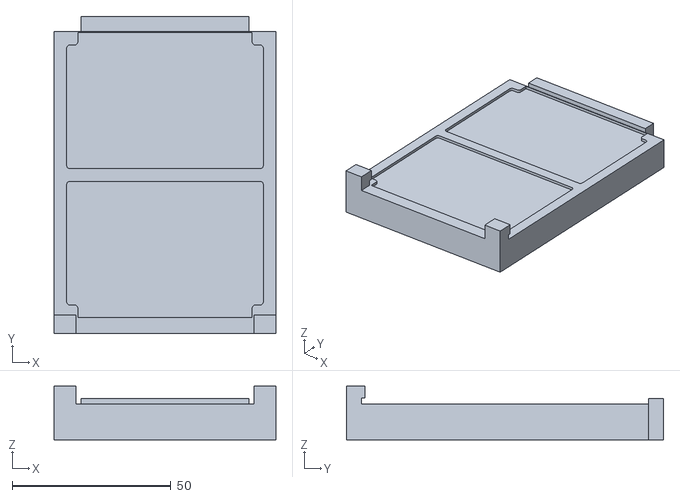
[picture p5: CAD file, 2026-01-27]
mech/finglong.STL
70.0 x 100.0 x 17.0

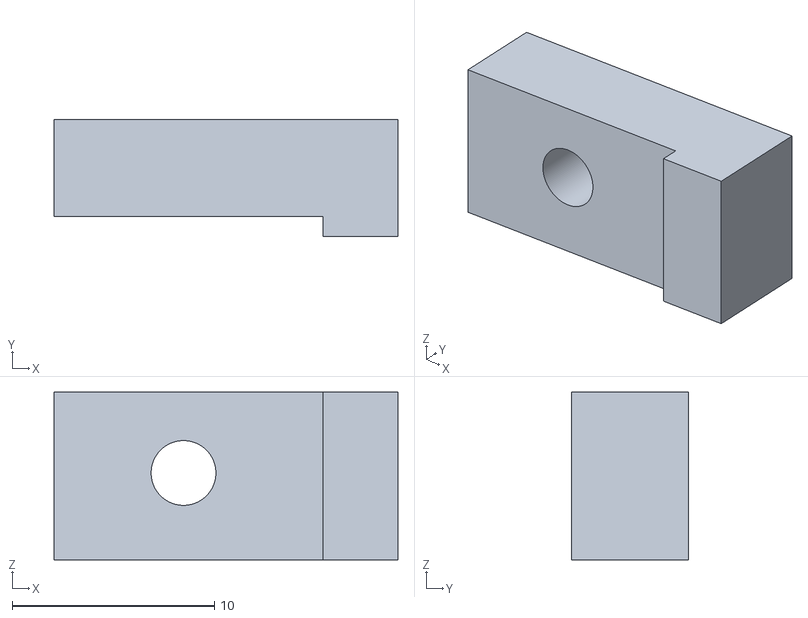
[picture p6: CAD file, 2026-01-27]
mech/2finglong.STL
17.0 x 5.80 x 8.30

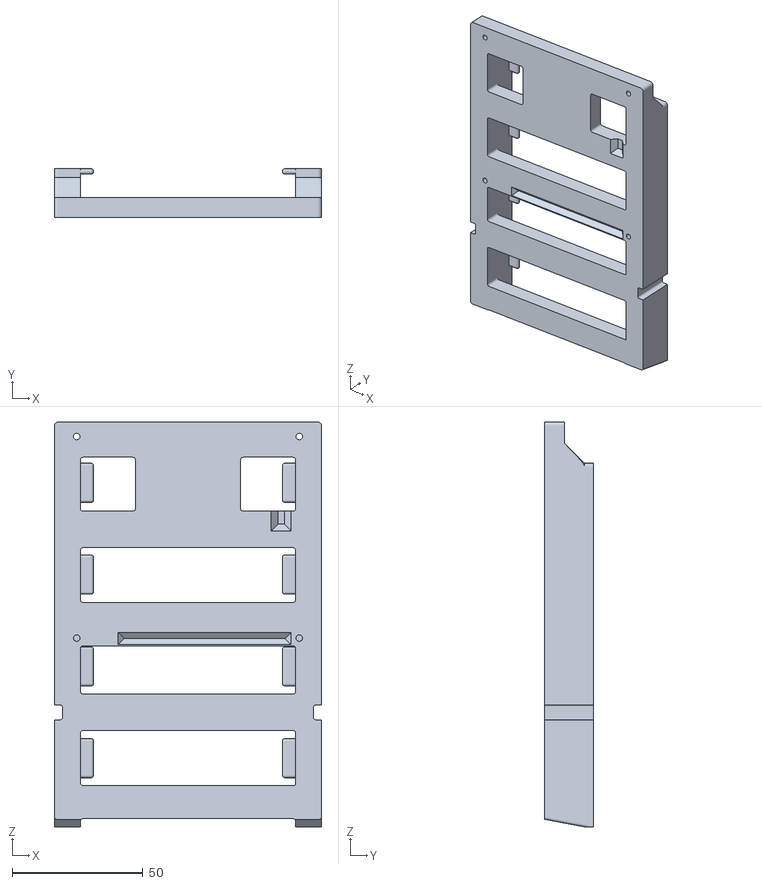
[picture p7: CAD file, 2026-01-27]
mech/difnif_PS2_drive_sled.STL
102.1 x 18.5 x 154.7

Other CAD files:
mech/df9f_carrier.STL

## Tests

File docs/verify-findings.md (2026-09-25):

# Checking the findings yourself

Each finding in [formfactor-review.md](formfactor-review.md) is listed below with
the evidence, where to look, and what you should see. Every check is against
**Eric's original files** and the manufacturers' or IBM's own documents, not the
modified files in this fork or the tools written for it.

Each finding is also labelled with the kind of claim it is:

- **File fact:** visible directly in Eric's schematic, board or Verilog.
- **Spec reading:** depends on reading a datasheet or IBM table correctly.
- **Simulation:** shown by this fork's testbench, which is only as good as its
  model (see "Reproducing the simulations").
- **Inference:** a reasonable conclusion, not proven.

## Setup

**Eric's untouched files.** `main` in this fork is still Eric's code
(commit `18a4d10`). A second checkout lets you open it in KiCad without touching
your working copy:

    git -C ~/Documents/networking/difnif worktree add ~/Documents/networking/difnif-original main

Open `~/Documents/networking/difnif-original/pcb_formfactor/DifNif.kicad_pro` in
KiCad. Close it without saving, so KiCad doesn't convert the files. You can also
view the files on GitHub at `schlae/difnif`.

**Following a net in KiCad.** In the schematic editor, click a wire or label and
press the backtick key (`` ` ``) to highlight everything on that net. In the PCB
editor, click a pad; the Properties panel shows its net.

**Documents:**

| Document | Where |
|---|---|
| IBM DBA-ESDI 72-pin connector pinout | https://ardent-tool.com/storage/DBA_ESDI.html |
| IBM PS/2 Hardware Interface Technical Reference, Micro Channel chapter (scanned) | https://ardent-tool.com/docs/pdf/ps2_50-60_techref_ch2_microchannel_architecture.pdf (PDF page *n* is book page 2-*n*) |
| Nexperia 74LVC4245A datasheet | https://assets.nexperia.com/documents/data-sheet/74LVC4245A.pdf |
| TI SN74LVC8T245 datasheet | https://www.ti.com/lit/ds/symlink/sn74lvc8t245.pdf |
| Eric's Micro Channel tutorial | https://github.com/schlae/mca-tutorial |

## The findings

### 1. The FPGA's `chreset` input is floating

- **Pinout (spec reading):** in the ardent-tool table, **B14 is `CHRESET`**, with
  no minus sign, so it's active high.
- **Schematic (file fact):** on the `DifNifBus` sheet, J1 pin b14 carries the label
  `~{CHRESET}_5V`, which goes to **U8 pin 14**. U8 pin 15 has the label
  `CHRESET_5V`. Highlight that net: **nothing else is on it**.
- **Board (file fact):** in the PCB editor, U8 pad 15 has no track.
- **Verilog (file fact):** `verilog/difnif.pcf` puts `chreset` on FPGA pin 76, which
  the schematic connects to U8 pin 9 (U8 pin 15's partner). `mcabus.v` line 385:
  `assign addressed = (~addr_sel_l) & ~m_io_l & ~chreset;`. Every register access
  depends on it.
- **"Explains the 50Z problem" is an inference.** A floating input fits "register
  communications don't work correctly", but only a board can prove it. The Rev P1
  check is: bridge U8 pins 14 and 15, and see whether register access becomes
  reliable.

### 2. The 74LVC4245A supplies are swapped (both boards)

- **Datasheet (spec reading), Nexperia:**
  - The features list says "3 V bus (VCC(B))" and "5 V bus (VCC(A))".
  - The pin table puts **VCC(A) on pin 1** and **VCC(B) on pins 23 and 24**.
  - Table 4 (limiting values): **VCC(B) absolute maximum 4.6 V**.
  - Table 5: VCC(B) recommended maximum 3.6 V, with VCC(A) ≥ VCC(B).
- **Schematic (file fact):** hover over U6's power pins, or U7-U10 and U14. **Pin 1
  is on +3V3, pins 23/24 are on +5V.** It's the same on `pcb_thinkpad`.
- **The replacement (spec reading), TI SN74LVC8T245:** same pin numbers (pin 1 VCCA,
  pins 23/24 VCCB), with **both supplies allowed from 1.65 to 5.5 V**, and the same
  function table (DIR low: B to A).

### 3. `-ADL` isn't connected (resolved, not a bug)

- **Pinout:** A20 is `-ADL`; in Eric's schematic J1 a20 has a no-connect flag.
- **Why it doesn't matter (spec reading):** IBM Figure 2-34 (book pages 2-62/2-63)
  gives address and status hold times of **30 ns after -CMD falls (T9, T10)**, and
  note 2 allows latching "with the leading edge of -CMD". My first write-up
  overstated this; the review now marks it resolved.

### 4. `-CD SFDBK` isn't driven

- **Pinout:** B08 is `-CD SFDBK`, direction I (driven by the card).
- **Schematic (file fact):** J1 b8 has a no-connect flag.
- **Requirement (spec reading):** Figure 2-34, note 1 (book page 2-63): "All slaves
  must drive -CD SFDBK whenever selected".
- **Inference:** whether a 55SX or Model 70 actually *checks* it for disk I/O is
  unknown.

### 5. The address decode also answers at 0x3518

- **Verilog (file fact):** `difnif_top.v` line 112:
  `addr_sel_l <= ~(bus_a[15:4] == 12'h351);`. That compares A15-A4 only, so it
  matches 0x3510-0x351F.
- **Context (spec reading):** the ESDI registers are 8 bytes wide. 0x3518 is the
  alternate ESDI address, selected by POS. `mcabus.v` line 316's comment marks POS 2
  bit 1 as the "3510" choice.

### 6. A `wire` is assigned in an `always` block

- **Verilog (file fact):** `difnif_top.v` line 95 declares `wire addr_sel_l;`, and
  lines 108-114 assign it inside `always @ (*)`. Icarus Verilog refuses the file.

### 8. There's no key slot in the board outline

- **Board (file fact):** in the PCB editor, turn on the `User.Drawings` layer: a
  line marks the slot between pins 2 and 3. On `Edge.Cuts` there's no slot.
- **Fab files (file fact):** open `pcb_formfactor/fab/DifNifFormFactor-RevP1.zip`'s
  `DifNif-Edge_Cuts.gbr` in KiCad's GerbView. It's a plain rectangle.
- **Physical:** your WD-3158 and the 55SX cable are both keyed.

### 9. Write data is captured when -CMD falls

- **Verilog (file fact):** `mcabus.v` lines 411-446. The `always @ (negedge cmd_l)`
  block stores `bus_d` into `reg_cifr`, `reg_atn`, `reg_bcr`, `reg_dreg_write` and
  the POS registers.
- **Timing (spec reading):** Figure 2-34 (book page 2-63): **T17, write data setup
  to -CMD active, minimum 0 ns**; T18, write data hold from -CMD inactive, minimum
  30 ns. So data is only guaranteed valid *at* the falling edge, and for 30 ns
  after the rising edge.
- **That it fails (simulation):** see "Reproducing the simulations". It depends on
  the real planar giving close to 0 ns of setup. Eric's 50Z measurements show
  about 50 ns, so real machines may never hit it.
- **The link to the "shifted by one byte" write bug is an inference**, and a weak
  one.

### 10. POS bypass hides the adapter ID

- **Verilog (file fact):** `mcabus.v` line 9 has `` `define MCA_NO_POS ``. Line 385
  (the bypass version of `addressed`) leaves out `~cd_setup_l`, so the card never
  answers POS setup cycles, and the `DF9F` ID at line 313 is never readable.
- **"The 50Z/55SX/70 BIOS needs it" is an inference.** A real DBA-ESDI drive answers
  POS on these machines, but I haven't confirmed the BIOS insists on it.

### 12. The DMA request drops too late

- **Verilog (file fact):**
  - Line 339: `dma_requested` depends on `flag_treq`.
  - Line 249 and the lines after it: `flag_treq` is cleared through a two-stage
    synchronizer on the 50 MHz clock, which takes 40-60 ns.
  - Line 370: the card decides whether to compete on the rising edge of
    `ARB/-GNT`.
- **Timing (spec reading):** Figure 2-46 (book page 2-85): **T41, ARB/-GNT high from
  end of transfer, minimum 30 ns.**
- **That it bites (simulation):** only if a planar really re-arbitrates within about
  40 ns of a transfer ending. Real planars may be slower.

### 13. The card relies on re-arbitration after DMA

- **Inference from Verilog:** `dma_cycle` (line 370) only changes when `ARB/-GNT`
  rises, so after winning, the card treats I/O cycles as DMA until the next
  arbitration. That's fine if the planar always re-arbitrates after a transfer.
  Eric's own testbench (`mcabus_t.v`, around line 408) notes seeing that on the real
  50Z. A logic analyzer on real hardware would confirm it.

## Reproducing the simulations

The testbench, `verilog/difnif72_t.v`, is this fork's code. Its assumptions are
worth reading before trusting its results:

- Host timing is either IBM's Figure 2-34 limits or Eric's typical 50Z
  measurements.
- Each level-shifter pin gets a random delay of 1-7 ns (the datasheet range).
- The FPGA itself is simulated with zero internal delay.
- A floating input is modelled as "unknown", so the as-built board fails
  consistently in simulation, where real hardware would probably fail
  intermittently.

**Findings 1, 5, 9 and 10 before any fixes.** Check out the commit that added the
testbench but not the fixes (`be66ed4`), and run the quick matrix. It needs
oss-cad-suite; takes about 20 seconds.

    git -C ~/Documents/networking/difnif worktree add ~/Documents/networking/difnif-be66ed4 be66ed4
    cd ~/Documents/networking/difnif-be66ed4/verilog
    PATH=/opt/oss-cad-suite/bin:$PATH ./run_sim72.sh quick

Expected:

- The **as-built** rows fail nearly every test (finding 1).
- The **bridged / bypass** rows fail the POS tests (finding 10) and "no response at
  3518" (finding 5).
- The **bridged / enabled / limit** rows fail the host-write tests (CIFR, ATN, DREG
  writes, POS write): finding 9.
- With POS enabled, typical timing passes everything except the 0x3518 test.

**Finding 12.** The DMA tests arrived in the same commit as the fix (`53ea7dd`), so
to see the failure, undo the fix by hand in a scratch checkout:

    git -C ~/Documents/networking/difnif worktree add ~/Documents/networking/difnif-53ea7dd 53ea7dd
    cd ~/Documents/networking/difnif-53ea7dd/verilog

In `mcabus.v`, change

    wire dma_requested = control_dma_enable & flag_treq & card_enable & ~treq_pending;

back to Eric's

    wire dma_requested = control_dma_enable & flag_treq & card_enable;

then run `PATH=/opt/oss-cad-suite/bin:$PATH ./run_sim72.sh quick`. At IBM limits the
DMA tests fail with "card re-entered arbitration with a stale request"; at typical
timing they pass.

**Cleaning up** afterwards (the worktrees are just extra folders):

    git -C ~/Documents/networking/difnif worktree remove ~/Documents/networking/difnif-be66ed4 --force
    git -C ~/Documents/networking/difnif worktree remove ~/Documents/networking/difnif-53ea7dd --force
    git -C ~/Documents/networking/difnif worktree remove ~/Documents/networking/difnif-original

## Mistakes made during this review

Knowing where the reasoning went wrong before helps judge the rest:

- I first called the missing `-ADL` a timing hazard (finding 3). IBM's tables
  showed latching on `-CMD` is allowed.
- Three times the testbench reported failures that were bugs in the testbench
  itself: a shared loop counter, an end-of-test handshake in the wrong order, and a
  missing arbitration cycle in the DMA controller model. Each was traced in the
  waveforms and fixed before any result was reported.
- An early photo estimate put the IBM drive's fingers at 1.3 mm wide. You measured
  1.5 mm, matching Eric's footprint.
- The first `-CD SFDBK` wiring cut part of the ground pour off and was changed
  during layout.

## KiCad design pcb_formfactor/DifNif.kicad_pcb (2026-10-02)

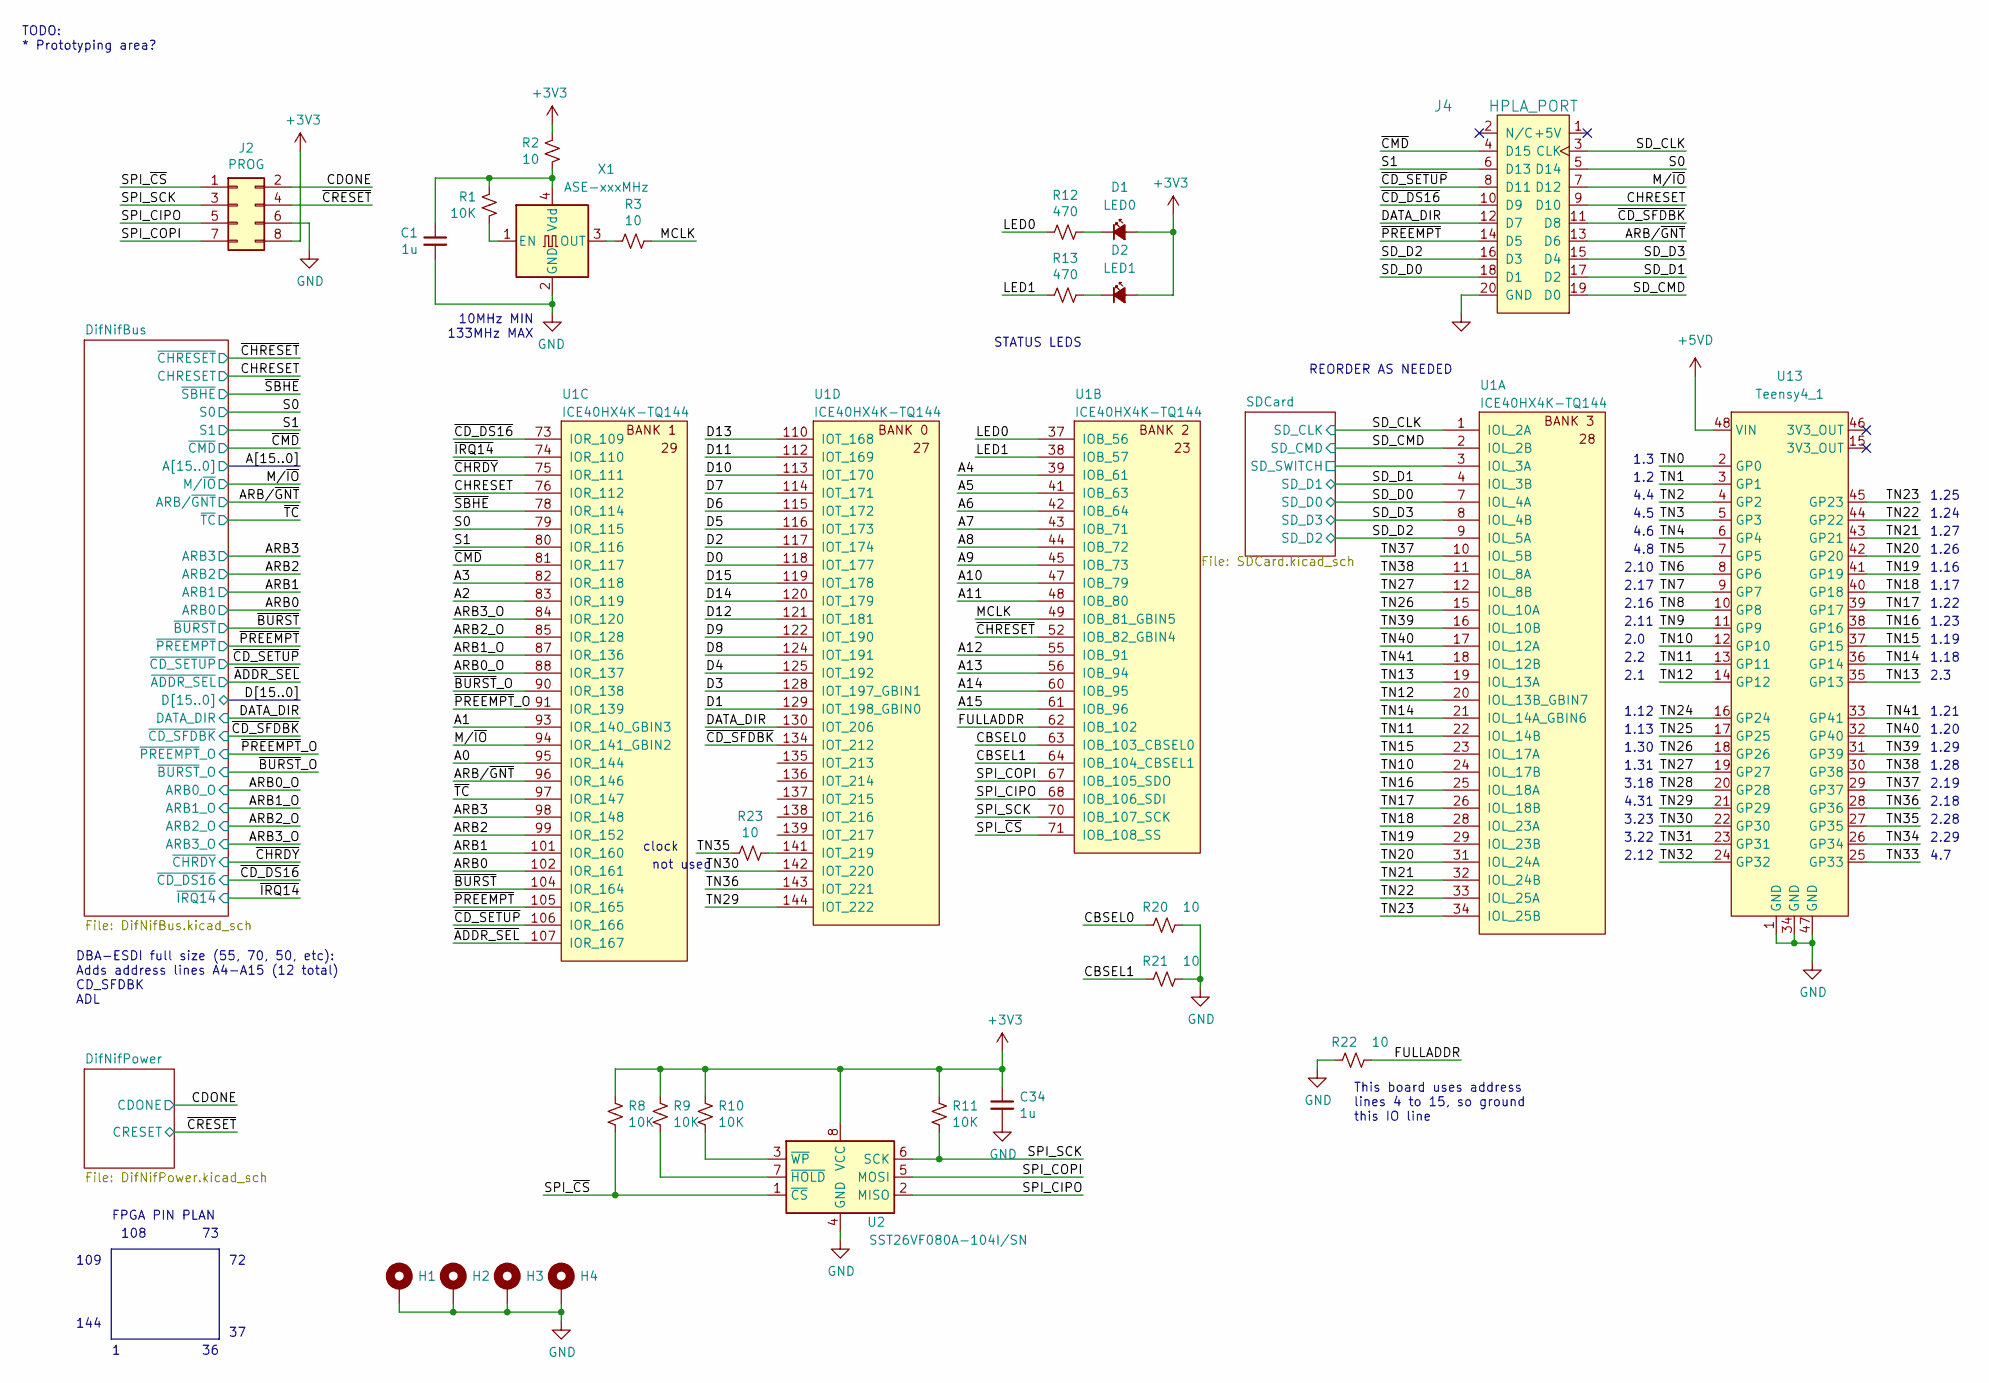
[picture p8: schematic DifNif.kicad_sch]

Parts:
C1, C34: 1u; CAPC1608X100; Mouser 810-CGA3E1X7R1C105AC
D1: LED0; LEDM1608X50
D2: LED1; LEDM1608X50
H1, H2, H3, H4: MountingHole_Pad; MountingHole_2.7mm_Pad
J2: PROG; PinHeader_2x04_P2.54mm_Vertical
J4: HPLA_PORT; PinHeader_2x10_P2.54mm_Vertical
R1, R8, R9, R10, R11: 10K; RESC1608X55; Mouser 603-RC0603FR-0710KL
R2, R3, R20, R21, R22, R23: 10; RESC1608X55; Mouser 603-RC0603FR-0710RL
R12, R13: 470; RESC1608X55; Mouser 603-RC0603FR-07470RL
U1: ICE40HX4K-TQ144; TSQFP50P2200X2200X160-144; Mouser 842-ICE40HX4K-TQ144
U2: SST26VF080A-104I/SN; SOP127P620X175-8; Mouser 579-26VF080A-104I/SN
U13: Teensy4_1; DIP-48_W15.24mm_Socket
X1: ASE-xxxMHz; XTAL320X250X120-4; Mouser 520-ECS-2333-100-BNT

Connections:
+3V3: C34.1, D1.2 (A), D2.2 (A), J2.8, R2.1, R8.1, R9.1, R10.1, R11.1, U2.8 (VCC); also elsewhere on the board
+5VD: U13.48 (VIN); also elsewhere on the board
/A0: U1.95 (IOR_144); also elsewhere on the board
/A1: U1.93 (IOR_140_GBIN3); also elsewhere on the board
/A2: U1.83 (IOR_119); also elsewhere on the board
/A3: U1.82 (IOR_118); also elsewhere on the board
/A4: U1.39 (IOB_61); also elsewhere on the board
/A5: U1.41 (IOB_63); also elsewhere on the board
/A6: U1.42 (IOB_64); also elsewhere on the board
/A7: U1.43 (IOB_71); also elsewhere on the board
/A8: U1.44 (IOB_72); also elsewhere on the board
/A9: U1.45 (IOB_73); also elsewhere on the board
/A10: U1.47 (IOB_79); also elsewhere on the board
/A11: U1.48 (IOB_80); also elsewhere on the board
/A12: U1.55 (IOB_91); also elsewhere on the board
/A13: U1.56 (IOB_94); also elsewhere on the board
/A14: U1.60 (IOB_95); also elsewhere on the board
/A15: U1.61 (IOB_96); also elsewhere on the board
/ARB0: U1.102 (IOR_161); also elsewhere on the board
/ARB0_O: U1.88 (IOR_137); also elsewhere on the board
/ARB1: U1.101 (IOR_160); also elsewhere on the board
/ARB1_O: U1.87 (IOR_136); also elsewhere on the board
/ARB2: U1.99 (IOR_152); also elsewhere on the board
/ARB2_O: U1.85 (IOR_128); also elsewhere on the board
/ARB3: U1.98 (IOR_148); also elsewhere on the board
/ARB3_O: U1.84 (IOR_120); also elsewhere on the board
/ARB/~GNT: J4.13 (D6), U1.96 (IOR_146); also elsewhere on the board
/CBSEL0: R20.2, U1.63 (IOB_103_CBSEL0)
/CBSEL1: R21.2, U1.64 (IOB_104_CBSEL1)
/CDONE: J2.2; also elsewhere on the board
/CHRESET: J4.9 (D10), U1.76 (IOR_112); also elsewhere on the board
/D0: U1.118 (IOT_177); also elsewhere on the board
/D1: U1.129 (IOT_198_GBIN0); also elsewhere on the board
/D2: U1.117 (IOT_174); also elsewhere on the board
/D3: U1.128 (IOT_197_GBIN1); also elsewhere on the board
/D4: U1.125 (IOT_192); also elsewhere on the board
/D5: U1.116 (IOT_173); also elsewhere on the board
/D6: U1.115 (IOT_172); also elsewhere on the board
/D7: U1.114 (IOT_171); also elsewhere on the board
/D8: U1.124 (IOT_191); also elsewhere on the board
/D9: U1.122 (IOT_190); also elsewhere on the board
/D10: U1.113 (IOT_170); also elsewhere on the board
/D11: U1.112 (IOT_169); also elsewhere on the board
/D12: U1.121 (IOT_181); also elsewhere on the board
/D13: U1.110 (IOT_168); also elsewhere on the board
/D14: U1.120 (IOT_179); also elsewhere on the board
/D15: U1.119 (IOT_178); also elsewhere on the board
/DATA_DIR: J4.12 (D7), U1.130 (IOT_206); also elsewhere on the board
/FULLADDR: R22.1, U1.62 (IOB_102)
/LED0: R12.2, U1.37 (IOB_56)
/LED1: R13.2, U1.38 (IOB_57)
/MCLK: R3.1, U1.49 (IOB_81_GBIN5)
/M/~IO: J4.7 (D12), U1.94 (IOR_141_GBIN2); also elsewhere on the board
/S0: J4.5 (D14), U1.79 (IOR_115); also elsewhere on the board
/S1: J4.6 (D13), U1.80 (IOR_116); also elsewhere on the board
/SDCard/SD_SWITCH: U1.3 (IOL_3A); also elsewhere on the board
/SD_CLK: J4.3 (CLK), U1.1 (IOL_2A); also elsewhere on the board
/SD_CMD: J4.19 (D0), U1.2 (IOL_2B); also elsewhere on the board
/SD_D0: J4.18 (D1), U1.7 (IOL_4A); also elsewhere on the board
/SD_D1: J4.17 (D2), U1.4 (IOL_3B); also elsewhere on the board
/SD_D2: J4.16 (D3), U1.9 (IOL_5A); also elsewhere on the board
/SD_D3: J4.15 (D4), U1.8 (IOL_4B); also elsewhere on the board
/SPI_CIPO: J2.5, U1.68 (IOB_106_SDI), U2.2 (MISO)
/SPI_COPI: J2.7, U1.67 (IOB_105_SDO), U2.5 (MOSI)
/SPI_SCK: J2.3, R11.2, U1.70 (IOB_107_SCK), U2.6 (SCK)
/SPI_~CS: J2.1, R8.2, U1.71 (IOB_108_SS), U2.1 (~CS)
/TN0: U13.2 (GP0)
/TN1: U13.3 (GP1)
/TN2: U13.4 (GP2)
/TN3: U13.5 (GP3)
/TN4: U13.6 (GP4)
/TN5: U13.7 (GP5)
/TN6: U13.8 (GP6)
/TN7: U13.9 (GP7)
/TN8: U13.10 (GP8)
/TN9: U13.11 (GP9)
/TN10: U1.24 (IOL_17B), U13.12 (GP10)
/TN11: U1.22 (IOL_14B), U13.13 (GP11)
/TN12: U1.20 (IOL_13B_GBIN7), U13.14 (GP12)
/TN13: U1.19 (IOL_13A), U13.35 (GP13)
/TN14: U1.21 (IOL_14A_GBIN6), U13.36 (GP14)
/TN15: U1.23 (IOL_17A), U13.37 (GP15)
/TN16: U1.25 (IOL_18A), U13.38 (GP16)
/TN17: U1.26 (IOL_18B), U13.39 (GP17)
/TN18: U1.28 (IOL_23A), U13.40 (GP18)
/TN19: U1.29 (IOL_23B), U13.41 (GP19)
/TN20: U1.31 (IOL_24A), U13.42 (GP20)
/TN21: U1.32 (IOL_24B), U13.43 (GP21)
/TN22: U1.33 (IOL_25A), U13.44 (GP22)
/TN23: U1.34 (IOL_25B), U13.45 (GP23)
/TN24: U13.16 (GP24)
/TN25: U13.17 (GP25)
/TN26: U1.15 (IOL_10A), U13.18 (GP26)
/TN27: U1.12 (IOL_8B), U13.19 (GP27)
/TN28: U13.20 (GP28)
/TN29: U1.144 (IOT_222), U13.21 (GP29)
/TN30: U1.142 (IOT_220), U13.22 (GP30)
/TN31: U13.23 (GP31)
/TN32: U13.24 (GP32)
/TN33: U13.25 (GP33)
/TN34: U13.26 (GP34)
/TN35: R23.2, U13.27 (GP35)
/TN36: U1.143 (IOT_221), U13.28 (GP36)
/TN37: U1.10 (IOL_5B), U13.29 (GP37)
/TN38: U1.11 (IOL_8A), U13.30 (GP38)
/TN39: U1.16 (IOL_10B), U13.31 (GP39)
/TN40: U1.17 (IOL_12A), U13.32 (GP40)
/TN41: U1.18 (IOL_12B), U13.33 (GP41)
/~ADDR_SEL: U1.107 (IOR_167)
/~BURST: U1.104 (IOR_164); also elsewhere on the board
/~BURST_O: U1.90 (IOR_138); also elsewhere on the board
/~CD_DS16: J4.10 (D9), U1.73 (IOR_109); also elsewhere on the board
/~CD_SETUP: J4.8 (D11), U1.106 (IOR_166); also elsewhere on the board
/~CD_SFDBK: J4.11 (D8), U1.134 (IOT_212); also elsewhere on the board
/~CHRDY: U1.75 (IOR_111); also elsewhere on the board
/~CHRESET: U1.52 (IOB_82_GBIN4); also elsewhere on the board
/~CMD: J4.4 (D15), U1.81 (IOR_117); also elsewhere on the board
/~CRESET: J2.4; also elsewhere on the board
/~IRQ14: U1.74 (IOR_110); also elsewhere on the board
/~PREEMPT: J4.14 (D5), U1.105 (IOR_165); also elsewhere on the board
/~PREEMPT_O: U1.91 (IOR_139); also elsewhere on the board
/~SBHE: U1.78 (IOR_114); also elsewhere on the board
/~TC: U1.97 (IOR_147); also elsewhere on the board
GND: C1.2, C34.2, H1.1, H2.1, H3.1, H4.1, J2.6, J4.20 (GND), R20.1, R21.1, R22.2, U2.4 (GND), U13.1 (GND), U13.34 (GND), U13.47 (GND), X1.2 (GND); also elsewhere on the board
unnamed: D1.1 (K), R12.1
unnamed: D2.1 (K), R13.1
unnamed: R23.1, U1.141 (IOT_219)
unnamed: R9.2, U2.7 (~HOLD)
unnamed: R10.2, U2.3 (~WP)
unnamed: R1.2, X1.1 (EN)
unnamed: R3.2, X1.3 (OUT)
unnamed: C1.1, R1.1, R2.2, X1.4 (Vdd)

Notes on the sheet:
2.1
2.19
4.31
1.16
2.17
2.18
1.30
2.16
1.27
clock
1.2
REORDER AS NEEDED
2.3
2.0
3.22
STATUS LEDS
TODO: * Prototyping area?
4.7
1.31
1.21
2.28
1.24
1.29
1.19
4.6
2.12
2.10
3.18
1.17
3.23
1.3
1.25
4.5
1.20
2.29
2.11
4.4
1.18
1.28
2.2

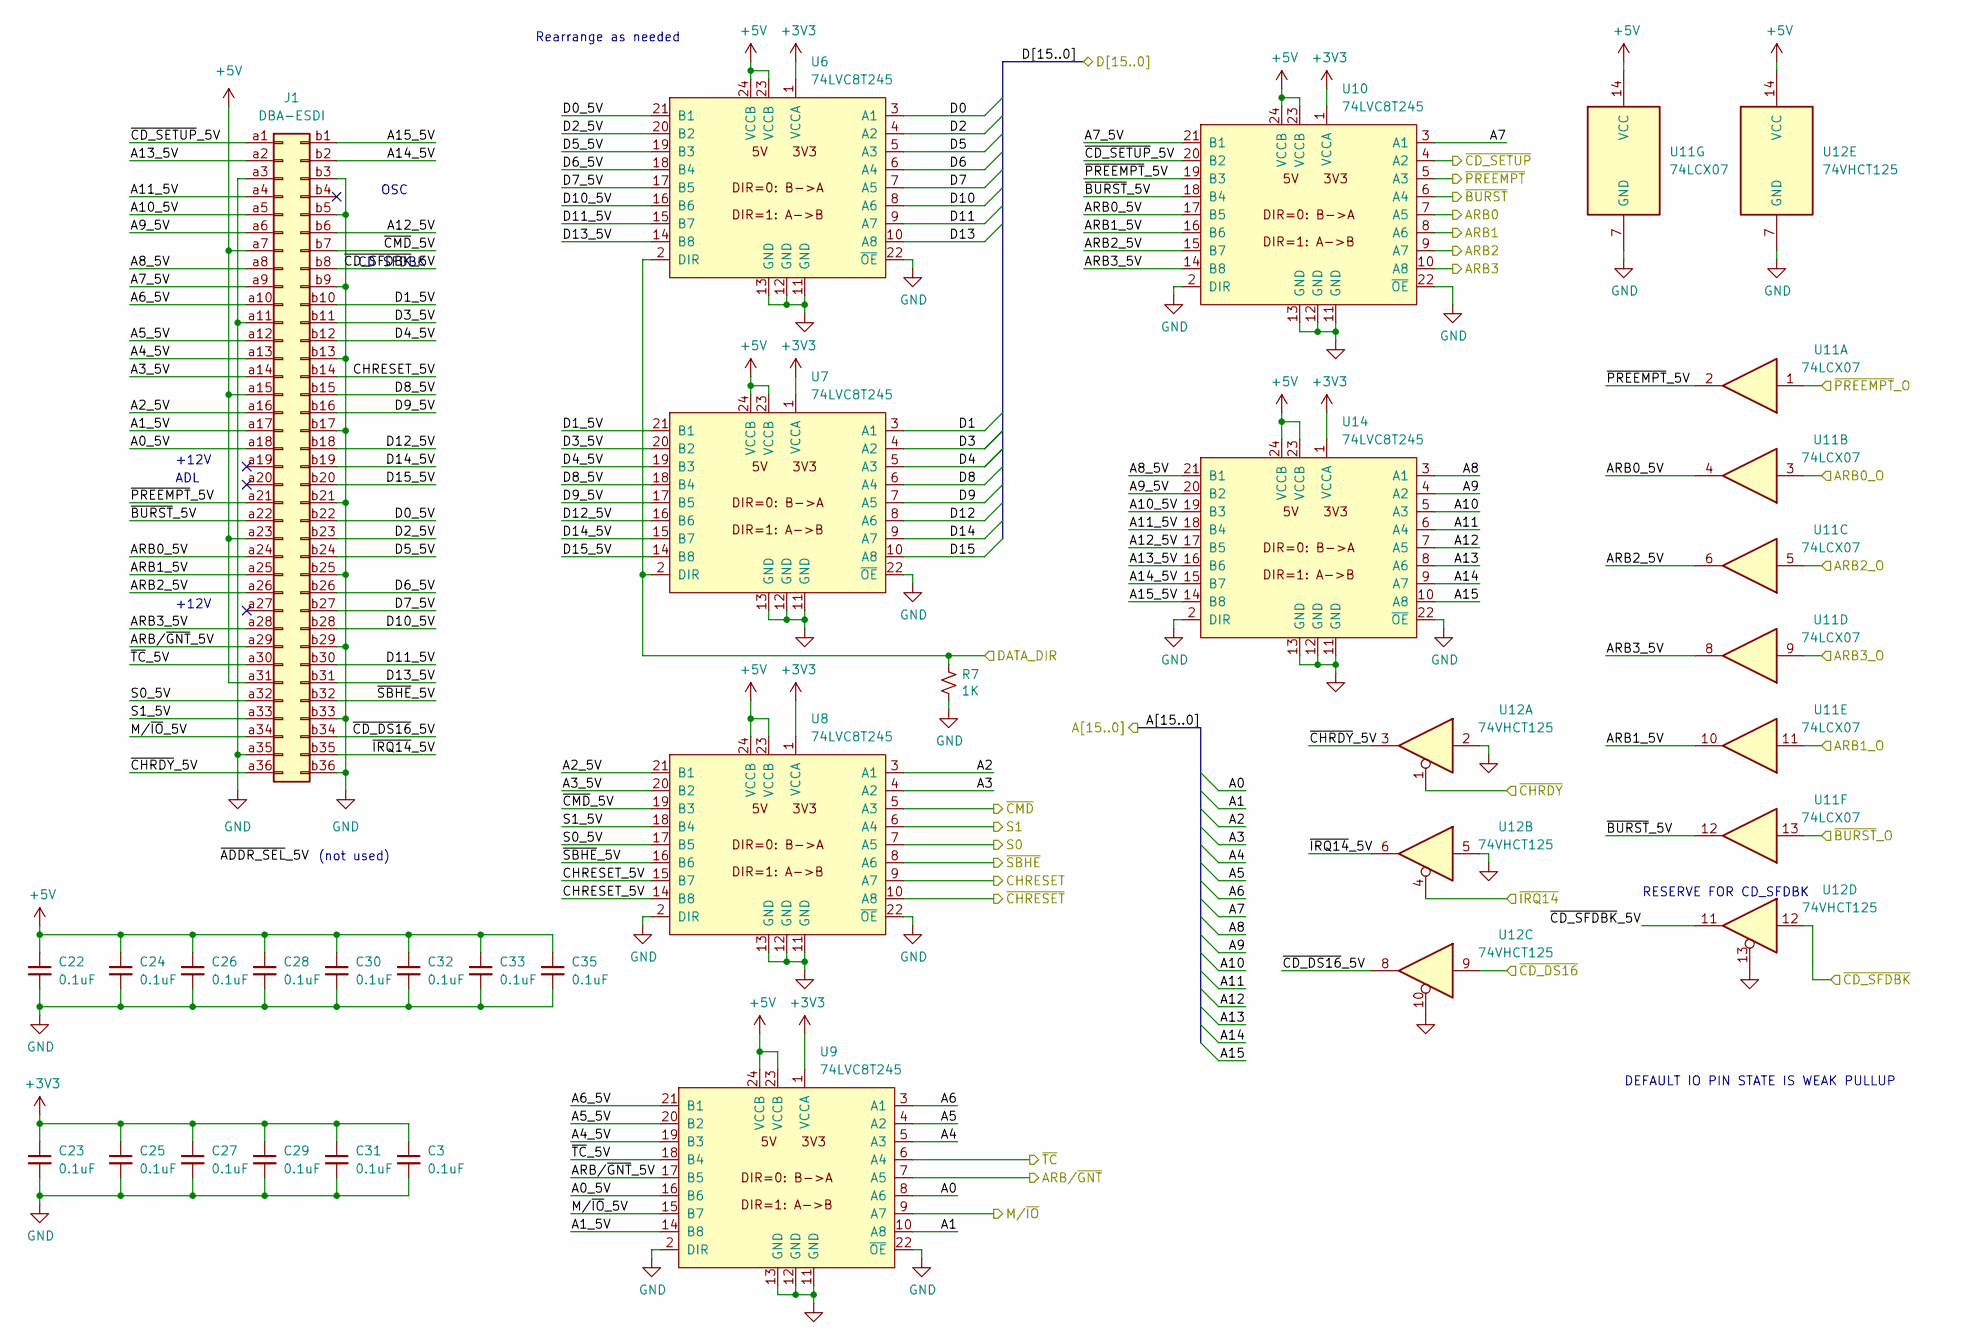
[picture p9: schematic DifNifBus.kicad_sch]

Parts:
C3, C22, C23, C24, C25, C26, C27, C28, C29, C30, C31, C32, C33, C35: 0.1uF; CAPC1608X100
J1: DBA-ESDI; BUS_DBA_ESDI
R7: 1K; RESC1608X55; Mouser 603-RC0603FR-071KL
U6, U7, U8, U9, U10, U14: 74LVC8T245; TSOP65P640X120-24; Mouser 595-SN74LVC8T245PWR
U11: 74LCX07; TSOP65P640X110-14; Mouser 757-74LCX07FTAE
U12: 74VHCT125; TSOP65P640X110-14; Mouser 757-74VHCT125AFT

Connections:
+3V3: C3.1, C23.1, C25.1, C27.1, C29.1, C31.1, U6.1 (VCCA), U7.1 (VCCA), U8.1 (VCCA), U9.1 (VCCA), U10.1 (VCCA), U14.1 (VCCA); also elsewhere on the board
+5V: C22.1, C24.1, C26.1, C28.1, C30.1, C32.1, C33.1, C35.1, J1.a7, J1.a15, J1.a23, J1.a31, U6.23 (VCCB), U6.24 (VCCB), U7.23 (VCCB), U7.24 (VCCB), U8.23 (VCCB), U8.24 (VCCB), U9.23 (VCCB), U9.24 (VCCB), U10.23 (VCCB), U10.24 (VCCB), U11.14 (VCC), U12.14 (VCC), U14.23 (VCCB), U14.24 (VCCB); also elsewhere on the board
/A0: U9.8 (A5); also elsewhere on the board
/A1: U9.10 (A7); also elsewhere on the board
/A2: U8.3 (A0); also elsewhere on the board
/A3: U8.4 (A1); also elsewhere on the board
/A4: U9.5 (A2); also elsewhere on the board
/A5: U9.4 (A1); also elsewhere on the board
/A6: U9.3 (A0); also elsewhere on the board
/A7: U10.3 (A0); also elsewhere on the board
/A8: U14.3 (A0); also elsewhere on the board
/A9: U14.4 (A1); also elsewhere on the board
/A10: U14.5 (A2); also elsewhere on the board
/A11: U14.6 (A3); also elsewhere on the board
/A12: U14.7 (A4); also elsewhere on the board
/A13: U14.8 (A5); also elsewhere on the board
/A14: U14.9 (A6); also elsewhere on the board
/A15: U14.10 (A7); also elsewhere on the board
/ARB0: U10.7 (A4); also elsewhere on the board
/ARB0_O: U11.3; also elsewhere on the board
/ARB1: U10.8 (A5); also elsewhere on the board
/ARB1_O: U11.11; also elsewhere on the board
/ARB2: U10.9 (A6); also elsewhere on the board
/ARB2_O: U11.5; also elsewhere on the board
/ARB3: U10.10 (A7); also elsewhere on the board
/ARB3_O: U11.9; also elsewhere on the board
/ARB/~GNT: U9.7 (A4); also elsewhere on the board
/CHRESET: U8.9 (A6); also elsewhere on the board
/D0: U6.3 (A0); also elsewhere on the board
/D1: U7.3 (A0); also elsewhere on the board
/D2: U6.4 (A1); also elsewhere on the board
/D3: U7.4 (A1); also elsewhere on the board
/D4: U7.5 (A2); also elsewhere on the board
/D5: U6.5 (A2); also elsewhere on the board
/D6: U6.6 (A3); also elsewhere on the board
/D7: U6.7 (A4); also elsewhere on the board
/D8: U7.6 (A3); also elsewhere on the board
/D9: U7.7 (A4); also elsewhere on the board
/D10: U6.8 (A5); also elsewhere on the board
/D11: U6.9 (A6); also elsewhere on the board
/D12: U7.8 (A5); also elsewhere on the board
/D13: U6.10 (A7); also elsewhere on the board
/D14: U7.9 (A6); also elsewhere on the board
/D15: U7.10 (A7); also elsewhere on the board
/DATA_DIR: R7.1, U6.2 (DIR), U7.2 (DIR); also elsewhere on the board
/DifNifBus/A0_5V: J1.a18, U9.16 (B5)
/DifNifBus/A1_5V: J1.a17, U9.14 (B7)
/DifNifBus/A2_5V: J1.a16, U8.21 (B0)
/DifNifBus/A3_5V: J1.a14, U8.20 (B1)
/DifNifBus/A4_5V: J1.a13, U9.19 (B2)
/DifNifBus/A5_5V: J1.a12, U9.20 (B1)
/DifNifBus/A6_5V: J1.a10, U9.21 (B0)
/DifNifBus/A7_5V: J1.a9, U10.21 (B0)
/DifNifBus/A8_5V: J1.a8, U14.21 (B0)
/DifNifBus/A9_5V: J1.a6, U14.20 (B1)
/DifNifBus/A10_5V: J1.a5, U14.19 (B2)
/DifNifBus/A11_5V: J1.a4, U14.18 (B3)
/DifNifBus/A12_5V: J1.b6, U14.17 (B4)
/DifNifBus/A13_5V: J1.a2, U14.16 (B5)
/DifNifBus/A14_5V: J1.b2, U14.15 (B6)
/DifNifBus/A15_5V: J1.b1, U14.14 (B7)
/DifNifBus/ARB0_5V: J1.a24, U10.17 (B4), U11.4
/DifNifBus/ARB1_5V: J1.a25, U10.16 (B5), U11.10
/DifNifBus/ARB2_5V: J1.a26, U10.15 (B6), U11.6
/DifNifBus/ARB3_5V: J1.a28, U10.14 (B7), U11.8
/DifNifBus/ARB/~GNT_5V: J1.a29, U9.17 (B4)
/DifNifBus/CHRESET_5V: J1.b14, U8.14 (B7), U8.15 (B6)
/DifNifBus/D0_5V: J1.b22, U6.21 (B0)
/DifNifBus/D1_5V: J1.b10, U7.21 (B0)
/DifNifBus/D2_5V: J1.b23, U6.20 (B1)
/DifNifBus/D3_5V: J1.b11, U7.20 (B1)
/DifNifBus/D4_5V: J1.b12, U7.19 (B2)
/DifNifBus/D5_5V: J1.b24, U6.19 (B2)
/DifNifBus/D6_5V: J1.b26, U6.18 (B3)
/DifNifBus/D7_5V: J1.b27, U6.17 (B4)
/DifNifBus/D8_5V: J1.b15, U7.18 (B3)
/DifNifBus/D9_5V: J1.b16, U7.17 (B4)
/DifNifBus/D10_5V: J1.b28, U6.16 (B5)
/DifNifBus/D11_5V: J1.b30, U6.15 (B6)
/DifNifBus/D12_5V: J1.b18, U7.16 (B5)
/DifNifBus/D13_5V: J1.b31, U6.14 (B7)
/DifNifBus/D14_5V: J1.b19, U7.15 (B6)
/DifNifBus/D15_5V: J1.b20, U7.14 (B7)
/DifNifBus/M/~IO_5V: J1.a34, U9.15 (B6)
/DifNifBus/S0_5V: J1.a32, U8.17 (B4)
/DifNifBus/S1_5V: J1.a33, U8.18 (B3)
/DifNifBus/~BURST_5V: J1.a22, U10.18 (B3), U11.12
/DifNifBus/~CD_DS16_5V: J1.b34, U12.8
/DifNifBus/~CD_SETUP_5V: J1.a1, U10.20 (B1)
/DifNifBus/~CD_SFDBK_5V: J1.b8, U12.11
/DifNifBus/~CHRDY_5V: J1.a36, U12.3
/DifNifBus/~CMD_5V: J1.b7, U8.19 (B2)
/DifNifBus/~IRQ14_5V: J1.b35, U12.6
/DifNifBus/~PREEMPT_5V: J1.a21, U10.19 (B2), U11.2
/DifNifBus/~SBHE_5V: J1.b32, U8.16 (B5)
/DifNifBus/~TC_5V: J1.a30, U9.18 (B3)
/M/~IO: U9.9 (A6); also elsewhere on the board
/S0: U8.7 (A4); also elsewhere on the board
/S1: U8.6 (A3); also elsewhere on the board
/~BURST: U10.6 (A3); also elsewhere on the board
/~BURST_O: U11.13; also elsewhere on the board
/~CD_DS16: U12.9; also elsewhere on the board
/~CD_SETUP: U10.4 (A1); also elsewhere on the board
/~CD_SFDBK: U12.12; also elsewhere on the board
/~CHRDY: U12.1; also elsewhere on the board
/~CHRESET: U8.10 (A7); also elsewhere on the board
/~CMD: U8.5 (A2); also elsewhere on the board
/~IRQ14: U12.4; also elsewhere on the board
/~PREEMPT: U10.5 (A2); also elsewhere on the board
/~PREEMPT_O: U11.1; also elsewhere on the board
/~SBHE: U8.8 (A5); also elsewhere on the board
/~TC: U9.6 (A3); also elsewhere on the board
GND: C3.2, C22.2, C23.2, C24.2, C25.2, C26.2, C27.2, C28.2, C29.2, C30.2, C31.2, C32.2, C33.2, C35.2, J1.a3, J1.a11, J1.a35, J1.b3, J1.b5, J1.b9, J1.b13, J1.b17, J1.b21, J1.b25, J1.b29, J1.b33, J1.b36, R7.2, U6.11 (GND), U6.12 (GND), U6.13 (GND), U6.22 (~OE), U7.11 (GND), U7.12 (GND), U7.13 (GND), U7.22 (~OE), U8.2 (DIR), U8.11 (GND), U8.12 (GND), U8.13 (GND), U8.22 (~OE), U9.2 (DIR), U9.11 (GND), U9.12 (GND), U9.13 (GND), U9.22 (~OE), U10.2 (DIR), U10.11 (GND), U10.12 (GND), U10.13 (GND), U10.22 (~OE), U11.7 (GND), U12.2, U12.5, U12.7 (GND), U12.10, U12.13, U14.2 (DIR), U14.11 (GND), U14.12 (GND), U14.13 (GND), U14.22 (~OE); also elsewhere on the board

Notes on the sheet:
Rearrange as needed
RESERVE FOR CD_SFDBK
+12V
(not used)
ADL
DEFAULT IO PIN STATE IS WEAK PULLUP
OSC
CD SFDBK

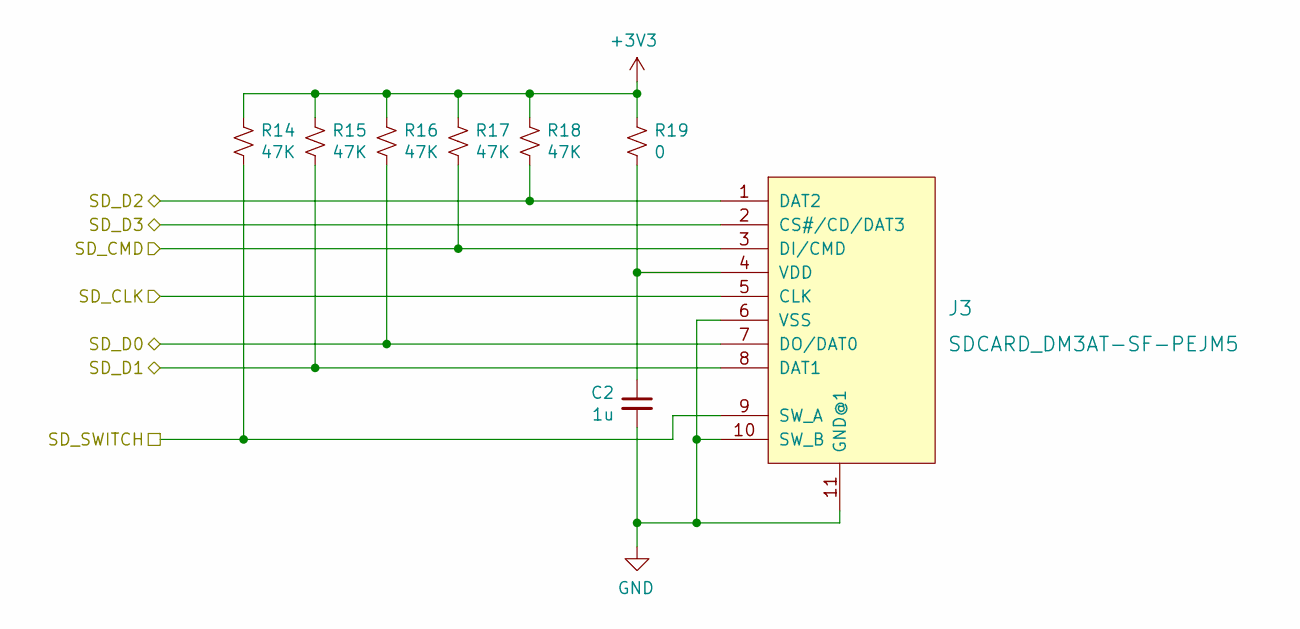
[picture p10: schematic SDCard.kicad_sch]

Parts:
C2: 1u; CAPC1608X100; Mouser 810-CGA3E1X7R1C105AC
J3: SDCARD_DM3AT-SF-PEJM5; microSD_HC_Hirose_DM3AT-SF-PEJM5; Mouser 798-DM3AT-SF-PEJM540
R14, R15, R16, R17, R18: 47K; RESC1608X55; Mouser 603-RC0603FR-0747KL
R19: 0; RESC2012X55; Mouser 603-RC0805FR-070RL

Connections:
+3V3: R14.1, R15.1, R16.1, R17.1, R18.1, R19.1; also elsewhere on the board
/SDCard/SD_SWITCH: J3.9 (SW_A), R14.2; also elsewhere on the board
/SD_CLK: J3.5 (CLK); also elsewhere on the board
/SD_CMD: J3.3 (DI/CMD), R17.2; also elsewhere on the board
/SD_D0: J3.7 (DO/DAT0), R16.2; also elsewhere on the board
/SD_D1: J3.8 (DAT1), R15.2; also elsewhere on the board
/SD_D2: J3.1 (DAT2), R18.2; also elsewhere on the board
/SD_D3: J3.2 (CS#/CD/DAT3); also elsewhere on the board
GND: C2.2, J3.6 (VSS), J3.10 (SW_B), J3.11 (GND@1); also elsewhere on the board
unnamed: C2.1, J3.4 (VDD), R19.2

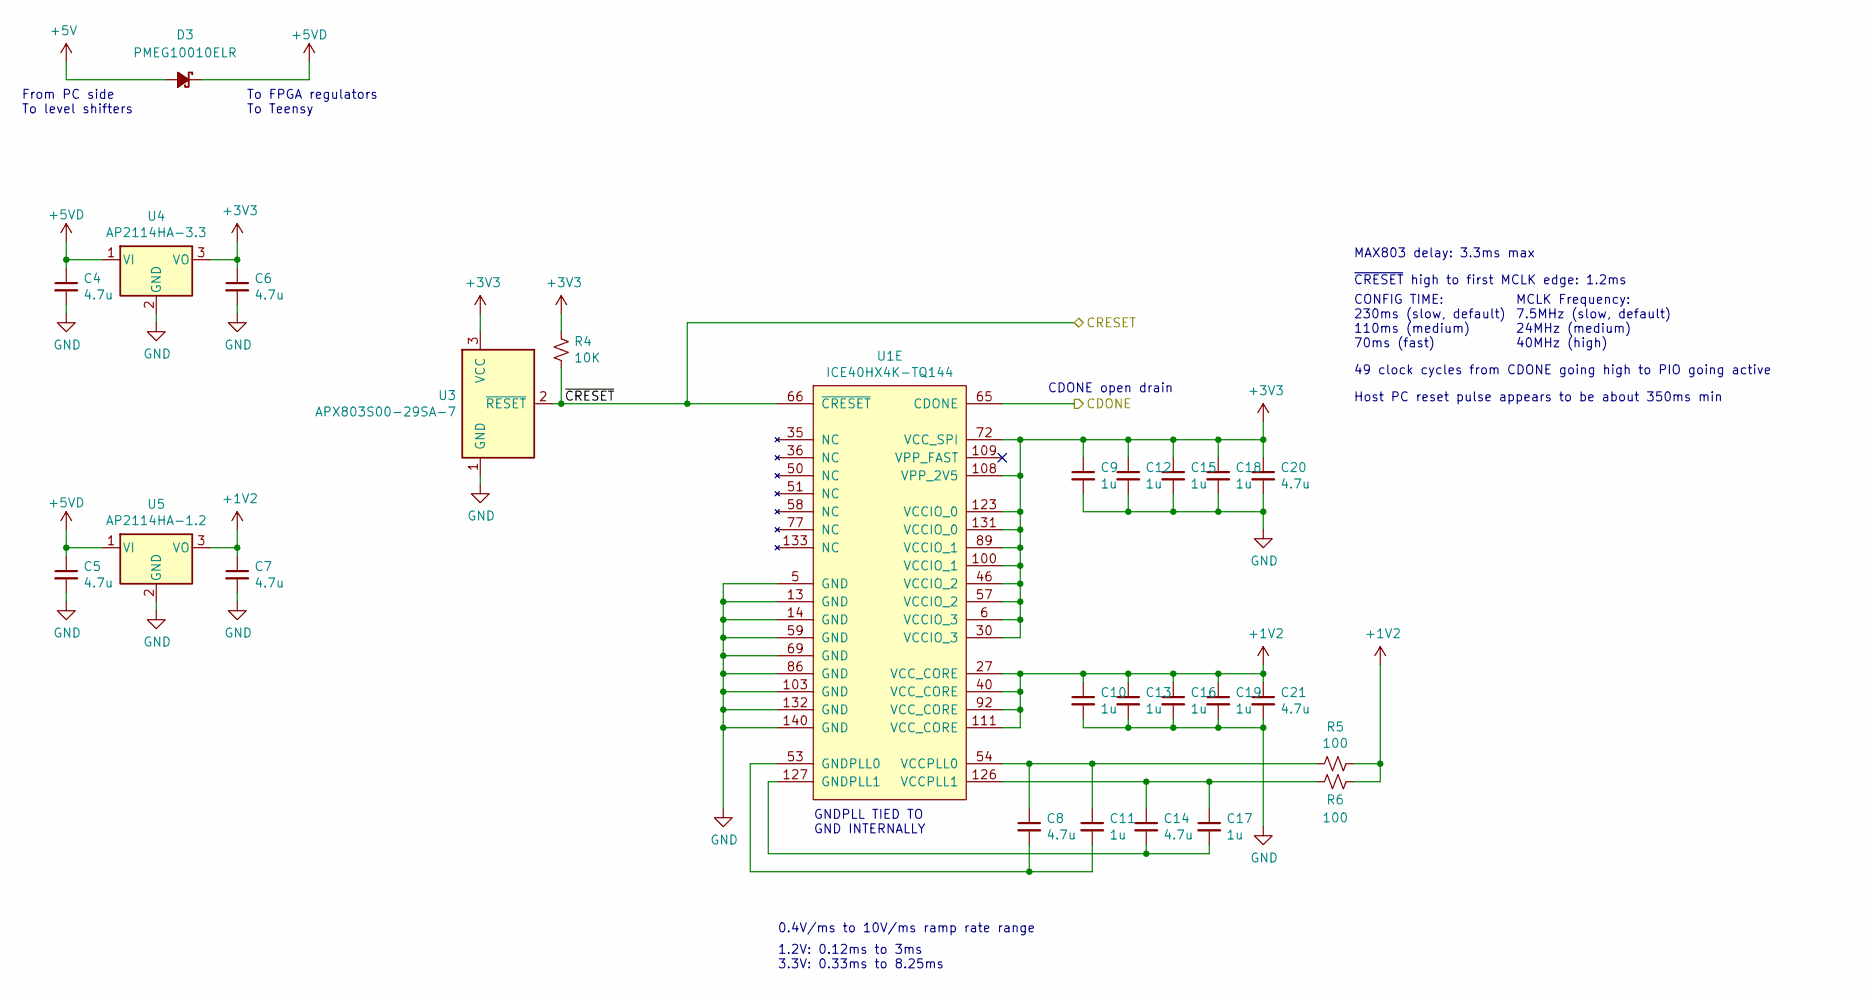
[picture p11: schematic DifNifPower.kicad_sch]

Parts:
C4, C5, C6, C7, C8, C14, C20, C21: 4.7u; CAPC1608X100; Mouser 187-CL10A475KP8NNNC
C9, C10, C11, C12, C13, C15, C16, C17, C18, C19: 1u; CAPC1608X100; Mouser 810-CGA3E1X7R1C105AC
D3: PMEG10010ELR; SOD3716X117; Mouser 771-PMEG10010ELRX
R4: 10K; RESC1608X55; Mouser 603-RC0603FR-0710KL
R5, R6: 100; RESC1608X55; Mouser 603-RC0603FR-07100RL
U1: ICE40HX4K-TQ144; TSQFP50P2200X2200X160-144; Mouser 842-ICE40HX4K-TQ144
U3: APX803S00-29SA-7; SOT95P230X117-3; Mouser 621-APX803S00-29SA-7
U4: AP2114HA-3.3; SOT230P700X170-3; Mouser 621-AP2114HA-3.3TRG1
U5: AP2114HA-1.2; SOT230P700X170-3; Mouser 621-AP2114HA-1.2TRG1

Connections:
+1V2: C7.1, C10.1, C13.1, C16.1, C19.1, C21.1, R5.1, R6.1, U1.27 (VCC_CORE), U1.40 (VCC_CORE), U1.92 (VCC_CORE), U1.111 (VCC_CORE), U5.3 (VO)
+3V3: C6.1, C9.1, C12.1, C15.1, C18.1, C20.1, R4.1, U1.6 (VCCIO_3), U1.30 (VCCIO_3), U1.46 (VCCIO_2), U1.57 (VCCIO_2), U1.72 (VCC_SPI), U1.89 (VCCIO_1), U1.100 (VCCIO_1), U1.108 (VPP_2V5), U1.123 (VCCIO_0), U1.131 (VCCIO_0), U3.3 (VCC), U4.3 (VO); also elsewhere on the board
+5V: D3.2 (A); also elsewhere on the board
+5VD: C4.1, C5.1, D3.1 (K), U4.1 (VI), U5.1 (VI); also elsewhere on the board
/CDONE: U1.65 (CDONE); also elsewhere on the board
/~CRESET: R4.2, U1.66 (~CRESET), U3.2 (~RESET); also elsewhere on the board
GND: C4.2, C5.2, C6.2, C7.2, C9.2, C10.2, C12.2, C13.2, C15.2, C16.2, C18.2, C19.2, C20.2, C21.2, U1.5 (GND), U1.13 (GND), U1.14 (GND), U1.59 (GND), U1.69 (GND), U1.86 (GND), U1.103 (GND), U1.132 (GND), U1.140 (GND), U3.1 (GND), U4.2 (GND), U5.2 (GND); also elsewhere on the board
unnamed: C8.2, C11.2, U1.53 (GNDPLL0)
unnamed: C14.2, C17.2, U1.127 (GNDPLL1)
unnamed: C8.1, C11.1, R5.2, U1.54 (VCCPLL0)
unnamed: C14.1, C17.1, R6.2, U1.126 (VCCPLL1)

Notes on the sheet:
49 clock cycles from CDONE going high to PIO going active
Host PC reset pulse appears to be about 350ms min
To FPGA regulators To Teensy
CONFIG TIME: 230ms (slow, default) 110ms (medium) 70ms (fast)
MCLK Frequency: 7.5MHz (slow, default) 24MHz (medium) 40MHz (high)
CDONE open drain
GNDPLL TIED TO GND INTERNALLY
From PC side To level shifters
0.4V/ms to 10V/ms ramp rate range
1.2V: 0.12ms to 3ms 3.3V: 0.33ms to 8.25ms
~{CRESET} high to first MCLK edge: 1.2ms
MAX803 delay: 3.3ms max

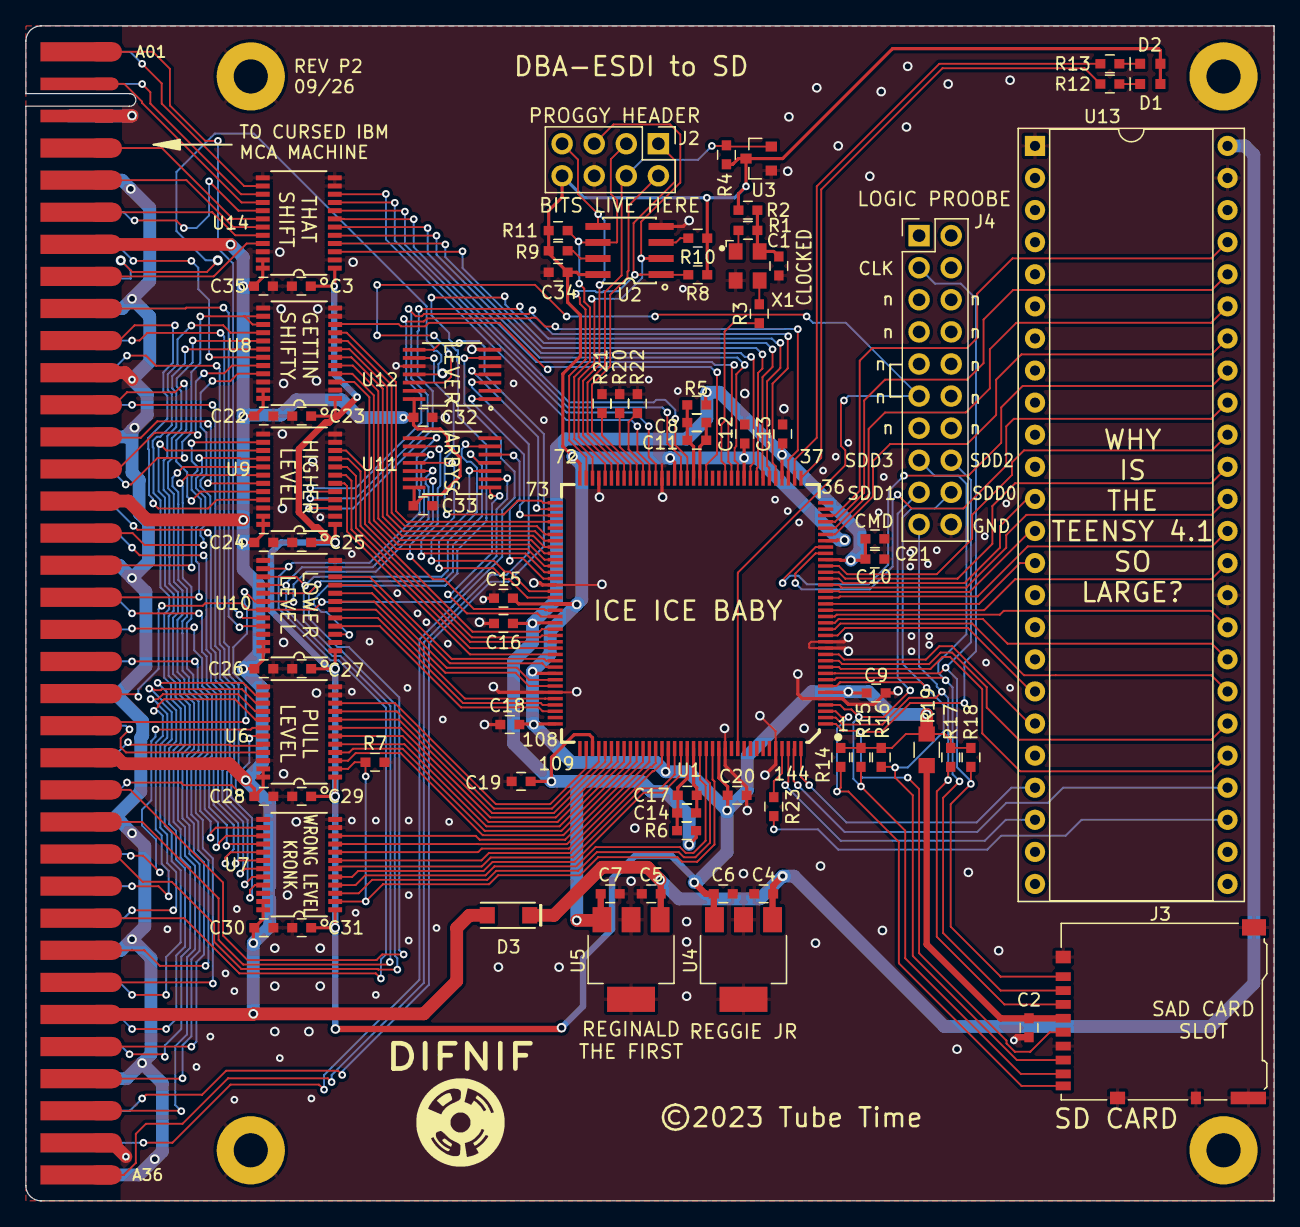
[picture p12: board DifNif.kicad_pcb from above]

Board: 2 copper layers, 98.8 x 93.0 mm, 84 parts (0 on the bottom side), 172 nets.

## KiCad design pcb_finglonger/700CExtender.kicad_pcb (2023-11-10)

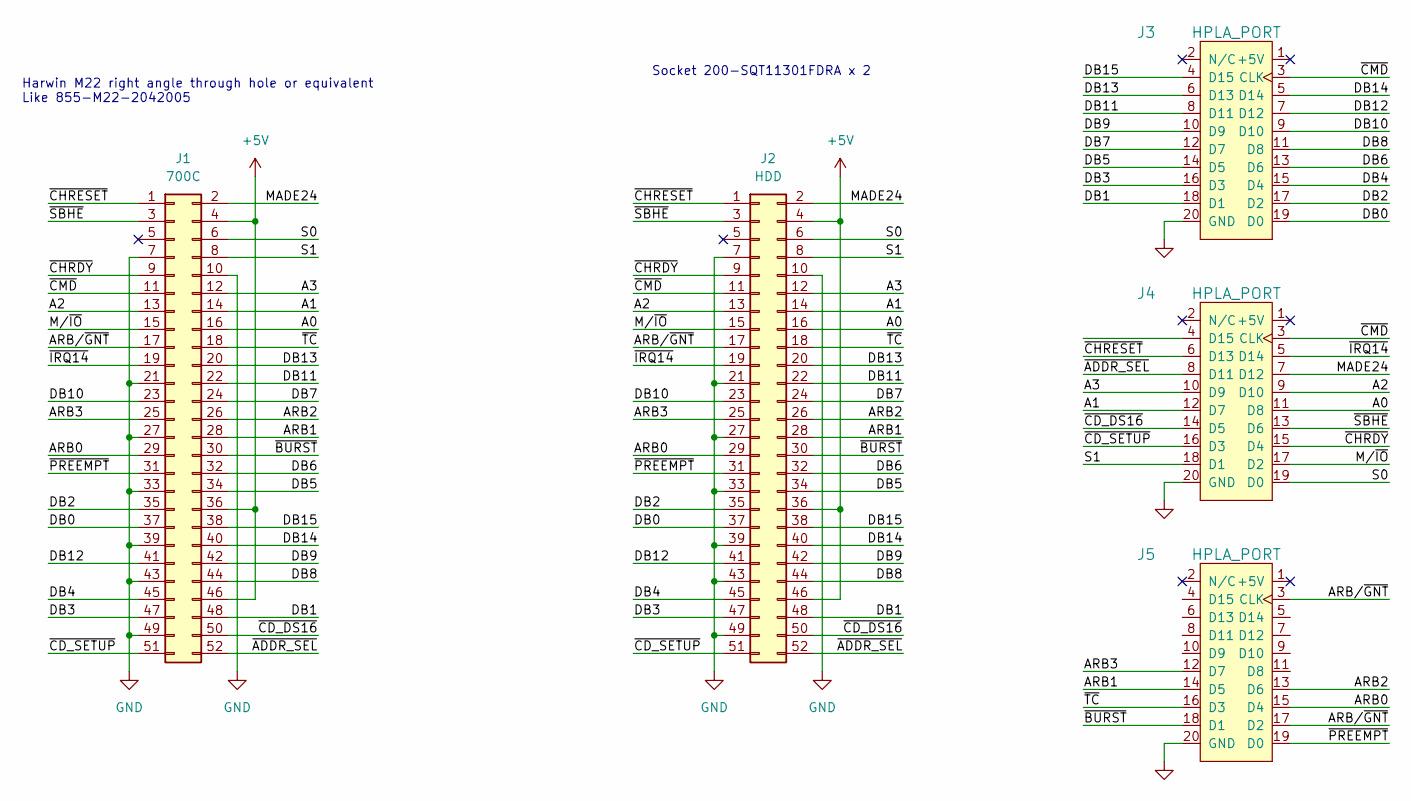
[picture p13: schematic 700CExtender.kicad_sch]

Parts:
J1: 700C; PinHeader_2x26_P2.00mm_Vertical
J2: HDD; PinSocket_2x26_P2.00mm_Vertical
J3, J4, J5: HPLA_PORT; PinHeader_2x10_P2.54mm_Vertical

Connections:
+5V: J1.4, J1.36, J1.46, J2.4, J2.36, J2.46
/A0: J1.16, J2.16, J4.11 (D8)
/A1: J1.14, J2.14, J4.12 (D7)
/A2: J1.13, J2.13, J4.9 (D10)
/A3: J1.12, J2.12, J4.10 (D9)
/ARB0: J1.29, J2.29, J5.15 (D4)
/ARB1: J1.28, J2.28, J5.14 (D5)
/ARB2: J1.26, J2.26, J5.13 (D6)
/ARB3: J1.25, J2.25, J5.12 (D7)
/ARB/~GNT: J1.17, J2.17, J5.3 (CLK), J5.17 (D2)
/DB0: J1.37, J2.37, J3.19 (D0)
/DB1: J1.48, J2.48, J3.18 (D1)
/DB2: J1.35, J2.35, J3.17 (D2)
/DB3: J1.47, J2.47, J3.16 (D3)
/DB4: J1.45, J2.45, J3.15 (D4)
/DB5: J1.34, J2.34, J3.14 (D5)
/DB6: J1.32, J2.32, J3.13 (D6)
/DB7: J1.24, J2.24, J3.12 (D7)
/DB8: J1.44, J2.44, J3.11 (D8)
/DB9: J1.42, J2.42, J3.10 (D9)
/DB10: J1.23, J2.23, J3.9 (D10)
/DB11: J1.22, J2.22, J3.8 (D11)
/DB12: J1.41, J2.41, J3.7 (D12)
/DB13: J1.20, J2.20, J3.6 (D13)
/DB14: J1.40, J2.40, J3.5 (D14)
/DB15: J1.38, J2.38, J3.4 (D15)
/MADE24: J1.2, J2.2, J4.7 (D12)
/M/~IO: J1.15, J2.15, J4.17 (D2)
/S0: J1.6, J2.6, J4.19 (D0)
/S1: J1.8, J2.8, J4.18 (D1)
/~ADDR_SEL: J1.52, J2.52, J4.8 (D11)
/~BURST: J1.30, J2.30, J5.18 (D1)
/~CD_DS16: J1.50, J2.50, J4.14 (D5)
/~CD_SETUP: J1.51, J2.51, J4.16 (D3)
/~CHRDY: J1.9, J2.9, J4.15 (D4)
/~CHRESET: J1.1, J2.1, J4.6 (D13)
/~CMD: J1.11, J2.11, J3.3 (CLK), J4.3 (CLK)
/~IRQ14: J1.19, J2.19, J4.5 (D14)
/~PREEMPT: J1.31, J2.31, J5.19 (D0)
/~SBHE: J1.3, J2.3, J4.13 (D6)
/~TC: J1.18, J2.18, J5.16 (D3)
GND: J1.7, J1.10, J1.21, J1.27, J1.33, J1.39, J1.43, J1.49, J2.7, J2.10, J2.21, J2.27, J2.33, J2.39, J2.43, J2.49, J3.20 (GND), J4.20 (GND), J5.20 (GND)

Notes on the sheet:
Harwin M22 right angle through hole or equivalent Like 855-M22-2042005
Socket 200-SQT11301FDRA x 2

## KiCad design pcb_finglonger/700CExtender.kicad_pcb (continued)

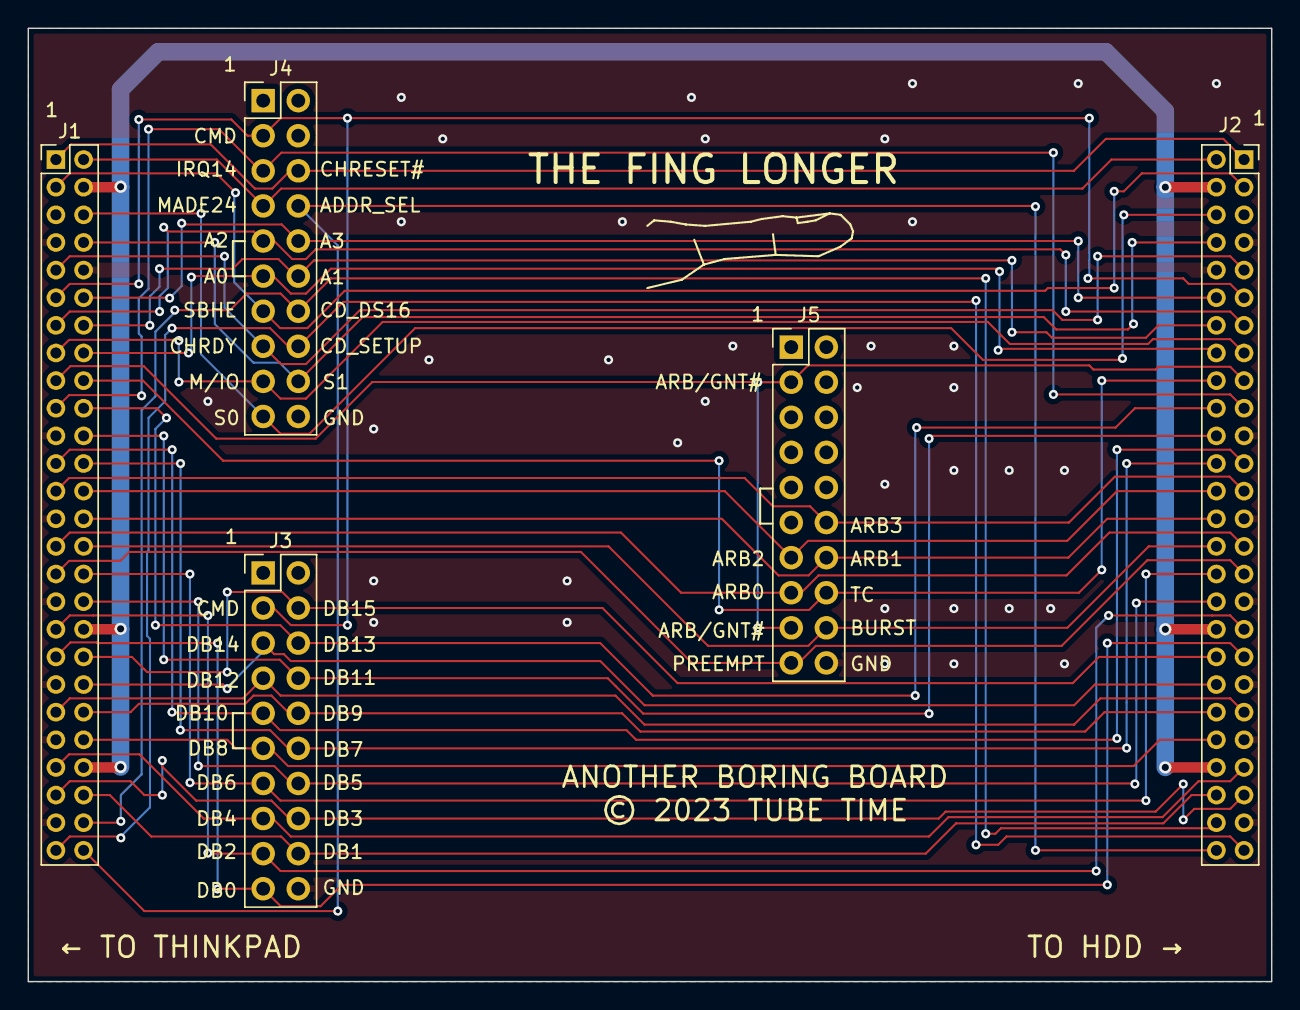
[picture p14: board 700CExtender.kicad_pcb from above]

Board: 2 copper layers, 90.0 x 69.0 mm, 5 parts (0 on the bottom side), 42 nets.

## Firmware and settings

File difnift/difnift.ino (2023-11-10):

#include <SD.h>


// Pin definitions
#define DEBUG_PIN 0
#define DEBUG_PIN2 1
#define PIN_CLK 35
#define PIN_RD 36
#define PIN_WR 37
#define PIN_INT 29
#define ADDR0 10
#define ADDR1 12
#define ADDR2 11
#define ADDR3 13

#define DPORT_MASK (0xFFFF0000)

// Register definitions for Teensy interface
#define REG_TEST 0
#define REG_FLAGS 1
#define REG_ATN 2
#define REG_ISR 3
#define REG_CIFR 4
#define REG_SIFR 5
#define REG_DREG 6
#define REG_POS01 7
#define REG_POS23 8
#define REG_POS4 9

// Bit definitions for REG_FLAGS
#define FLAG_ATN_FULL 0
#define FLAG_ISR_FULL 1
#define FLAG_CIFR_FULL 2
#define FLAG_SIFR_FULL 3
#define FLAG_HARD_RESET 4
#define FLAG_TREQ_SET 5
#define FLAG_CMD_PROG 6
#define FLAG_BUSY 7
#define FLAG_TREQ_STATE 8
#define FLAG_TRANSFER_16 9
#define FLAG_CLEAR_ALL 10

// Some ESDI-DBA values
#define DEV_CONTROLLER (0xE0)
#define DEV_DRIVE (0x00)

// ATN commands
#define ATN_COMMAND 0x1
#define ATN_EOI     0x2
#define ATN_ABORT   0x3
#define ATN_RESET   0x4

#define ATN_DEV_MASK 0xE0
#define ATN_CMD_MASK 0x0F

// ISR interrupt values
#define ISR_RESET_OK 0xEA
#define ISR_RESET_FAIL 0xFA
#define ISR_CMD_ERROR 0x0E
#define ISR_ATN_ERROR 0x0F
#define ISR_DATA_XFER_RDY 0x0B

// Command block values
#define CMD_NO_OPT_MASK (0xC0FF) // Page 29, ignores options field
#define CMD_CMD_MASK (0x001F)
#define CMD_DEV_MASK (0x00E0)

// Status block values
#define STAT_BLEN_MASK (0xFF00) // Page 50.
#define STAT_DEV_MASK (0x00E0)
#define STAT_CMD_MASK (0x001F)

// Pin definitions for 16-bit data port
const int portpin[] = {27, 26, 39, 38,
                        21, 20, 23, 22,
                        16, 17, 41, 40,
                        15, 14, 18, 19};

uint8_t oldint = 0; // only used in debug version of loop()

// Status and command block buffers
uint16_t status_block[8] = {0};
uint8_t status_count = 0;
uint8_t status_max = 0;
uint16_t cmd_block[8] = {0};
uint8_t cmd_count = 0;

// Data transfer buffer
uint8_t transfer_buffer[512];
uint16_t transfer_count = 0;
uint16_t transfer_index = 0;

#define TS_IDLE 0
#define TS_READ 1
#define TS_WRITE 2
uint8_t transfer_state = TS_IDLE;

// Interrupt state
#define PEND_INT 1
#define PEND_INT_RESET 2
uint8_t int_pending = 0;

// Status block fields
uint8_t sb_cmd_status = 0; // This is just ISR contents.
uint8_t sb_cmd_error = 0;
#define CMD_ERR_PARAM (0x1)
#define CMD_ERR_UNSUPP (0x3)
#define CMD_ERR_INVDEV (0x13)

uint8_t sb_dev_status = 0x19; // READY, SELECTED, cmd complete
uint8_t sb_dev_error = 0;
#define DEV_ERR_BADRBA (0x7)
#define DEV_ERR_NOTREADY (0x10)
uint8_t sb_por_error = 0;
uint8_t sb_test_error = 0;

// SD card stuff
SdFs sd;
FsFile file; 
bool has_sdcard;
uint32_t disk_size = 0; // In sectors/RBAs

uint32_t current_rba = 0;
uint32_t psu_rba_max = 0;
uint32_t rba_transfer_count = 0;
bool no_disk_op = false;

// Benchmarking
elapsedMicros since_sd_op;
elapsedMicros since_dma_start;

bool debugpinstate = false;
void debugPulse()
{
  digitalWriteFast(DEBUG_PIN, !debugpinstate);
  debugpinstate = !debugpinstate;
  //delayMicroseconds(1);
  //digitalWriteFast(DEBUG_PIN, 0);
}

bool debugpinstate2 = false;
void debugPulse2()
{
  digitalWriteFast(DEBUG_PIN2, !debugpinstate2);
  debugpinstate2 = !debugpinstate2;
  //delayMicroseconds(1);
  //digitalWriteFast(DEBUG_PIN, 0);
}


// Set 16-bit data port direction
void setPortMode(uint8_t mode)
{
    // We are using GPIO6 pins 16 to 31.
    if (mode == OUTPUT) {
      GPIO6_GDIR |= DPORT_MASK; // Set bits to '1' for output
    } else if (mode == INPUT) {
      GPIO6_GDIR &= ~DPORT_MASK; // Clear bits to '0' for input
    }
}


// Read a value from the FPGA port
uint16_t portRead(uint8_t address)
{
    uint16_t ret;
    digitalWriteFast(ADDR0, address & 1);
    digitalWriteFast(ADDR1, (address >> 1) & 1);
    digitalWriteFast(ADDR2, (address >> 2) & 1);
    digitalWriteFast(ADDR3, (address >> 3) & 1);
    digitalWriteFast(PIN_RD, 1);
    // If I want to go faster than 200ns, I will need to make this a synchronous
    // interface using a clock coming out of the FPGA.
    delayNanoseconds(200); //ES was 3us
    ret = GPIO6_PSR >> 16;
    // Grab port contents
    digitalWriteFast(PIN_RD, 0);
    return ret;
}


// Write a value to the FPGA port
void portWrite(uint8_t address, uint16_t data)
{
    digitalWriteFast(ADDR0, address & 1);
    digitalWriteFast(ADDR1, (address >> 1) & 1);
    digitalWriteFast(ADDR2, (address >> 2) & 1);
    digitalWriteFast(ADDR3, (address >> 3) & 1);
    setPortMode(OUTPUT);
    GPIO6_DR = (GPIO6_DR & 0xFFFF) | (data << 16);
    digitalWriteFast(PIN_WR, 1);
    delayNanoseconds(200); //ES was 3us
    digitalWriteFast(PIN_WR, 0);
    setPortMode(INPUT);
}


// Configure the device and print the menu options
void setup() {
  // put your setup code here, to run once:
  Serial.begin(115200);
  setPortMode(INPUT);
  pinMode(PIN_CLK, INPUT);
  pinMode(PIN_RD, OUTPUT);
  pinMode(PIN_WR, OUTPUT);
  pinMode(PIN_INT, INPUT);
  pinMode(ADDR0, OUTPUT);
  pinMode(ADDR1, OUTPUT);
  pinMode(ADDR2, OUTPUT);
  pinMode(ADDR3, OUTPUT);
  pinMode(DEBUG_PIN, OUTPUT);
  pinMode(DEBUG_PIN2, OUTPUT);

  if (!sd.begin(SdioConfig(FIFO_SDIO))) {
    Serial.println("No SD card found.");
    has_sdcard = false;
  }
  has_sdcard = true;

  Serial.println("Press 'f' for flag register contents.");
  Serial.println("Press 'F' to set flag register.");
  Serial.println("Press 'a' for ATN register contents.");
  Serial.println("Press 'i' to write to ISR and trig an interrupt.");
  Serial.println("Press 'c' to read Command Interface Reg.");
  Serial.println("Press 'C' for CIFR read loop test.");
  Serial.println("Press 'S' for SIFR write loop test.");
  Serial.println("Press 'A' for ATN read loop test.");
  Serial.println("Press 'I' for ISR write loop test.");
  Serial.println("Press '1' for Teensy-to-host loop test.");
  Serial.println("Press '2' for host-to-Teensy loop test.");
  Serial.println("Press 's' to write Status Interface Reg.");
  Serial.println("Hit 'q' to run the SD card filesystem test.");
  Serial.println("Press 'G' to run the main loop.");
}


// Sets up disk image file
int diskSetup() {
  uint64_t s;

  if (!has_sdcard) {
    return 1;
  }
  
  if (!file.open("disk0.img", O_RDWR)) {
    Serial.println("Can't open file.");
    return 1;
  }

  s = file.fileSize();

  if ((s % (512 * 2048)) != 0) {
    Serial.println("Warning: Image size not divisible by 1048576 (1MB), will be truncated.");
  }

  disk_size = (uint32_t)(s / 512 / 2048) * 2048; // Calculate number of RBAs in the image file

  if (disk_size > 0x1ff800) {
    Serial.println("Warning: Image size is > 1G (1023MB) and will be truncated.");
    disk_size = 0x1ff800;
  }

  if (s < 1) {
    Serial.println("Disk image is too small.");
    return 1;
  }

  Serial.print("Disk size (RBAs): ");
  Serial.println(disk_size, DEC);

  psu_rba_max = disk_size - 1; // Set pseudo RBA max to the disk size
  // FIXME: eventually store this value nonvolatile if directed to by the Set RBA Max command

  return 0;
}

int readDiskRBA(uint32_t rba)
{
  since_sd_op = 0;
  // ES testing, load all zeros for IML sectors!
  #if 0
  if (rba >= 0x3BD35 && rba <= 0x3BFFF) {
    memset(transfer_buffer, 0, 512);
    return 0;
  }
  #endif
  // TODO: check against file size limit
  if (!file.seek((uint64_t)rba * 512)) {
    return 1;
  }
  if (!file.read(transfer_buffer, 512)) {
    return 1;
  }
  Serial.print("rtime: ");
  Serial.println(since_sd_op);
  return 0;
}

int writeDiskRBA(uint32_t rba)
{
  since_sd_op = 0;
  // TODO: check against file size limit
  if (!file.seek((uint64_t)rba * 512)) {
    return 1;
  }
  if (!file.write(transfer_buffer, 512)) {
    return 1;
  }
  Serial.print("wtime: ");
  Serial.println(since_sd_op);
  return 0;
}

// Prints a 16-bit hex value to the USB console
void print16hex(uint16_t val)
{
    Serial.print(val >> 12, HEX);
    Serial.print((val >> 8) & 0xF, HEX);
    Serial.print((val >> 4) & 0xF, HEX);
    Serial.print(val & 0xF, HEX); 
}


// Reads a hex digit from the USB console
uint8_t readhex()
{
  char d;
  while(1) {
    if (Serial.available() > 0) {
      d = Serial.read();
      if ((d >= 0x30) && (d <= 0x39)) {
        return d - 0x30;
      }
      if ((d >= 0x41) && (d <= 0x46)) {
        return d + 0xA - 0x41;
      }
      if ((d >= 0x61) && (d <= 0x66)) {
        return d + 0xa - 0x61;
      }
    }
  }
}


// Reads 2 hex digits from the console
uint8_t read8()
{
  uint8_t d;
  d = readhex();
  Serial.print(d, HEX);
  d = (d << 4) | readhex();
  Serial.print(d & 0xF, HEX);
  return d;
}


// Reads 4 hex digits from the console
uint16_t read16()
{
  uint16_t d;
  d = readhex();
  Serial.print(d, HEX);
  d = (d << 4) | readhex();
  Serial.print(d & 0xF, HEX);
  d = (d << 4) | readhex();
  Serial.print(d & 0xF, HEX);
  d = (d << 4) | readhex();
  Serial.print(d & 0xF, HEX);
  return d;
}


// Checks first word of command block, returns length
uint8_t cmdBlockLen()
{
  uint16_t t = cmd_block[0] >> 14;
  if (t == 0) return 2;
  if (t == 1) return 4;
  // TODO: what if t is reserved?
  return 2;
}


// Loads the ISR with the code, updates the command status register
void doISR(uint16_t code)
{
  sb_cmd_status = code & 0xF;
  portWrite(REG_ISR, code);
}


// Fills in basic info for the status block
void startStatusBlock(uint8_t len, uint8_t code)
{
  status_block[0] = (len << 8) | code;
  status_count = 0;
  status_max = len;
}


// Writes a word of the status block to the host
void loadStatusBlock()
{
  status_max--;
  portWrite(REG_SIFR, status_block[status_count]);
  Serial.print("SIFR: count ");
  #if 0
  debugPulse();
  #endif
  Serial.println(status_count);
  status_count++;
}


// Set up the first part of the status block (page 49)
void prepDefaultSB()
{
  startStatusBlock(7, cmd_block[0]);
  status_block[1] = (sb_cmd_status << 8) | sb_cmd_error; // command status, command error code
  status_block[2] = (sb_dev_status << 8) | sb_dev_error; // device status, device error code
  status_block[3] = 0x0000;
  status_block[4] = current_rba & 0xffff; 
  status_block[5] = current_rba >> 16; 
  status_block[6] = 0x0000;
}


// Sets a bit in the FPGA flag register
void setFlag(uint16_t flag)
{
  uint16_t old;
  old = portRead(REG_FLAGS);
  portWrite(REG_FLAGS, old | flag);
}


// Clears a bit in the FPGA flag register
void clearFlag(uint16_t flag)
{
  uint16_t old;
  old = portRead(REG_FLAGS);
  portWrite(REG_FLAGS, old & ~flag);
}


// Sets up a pending interrupt to the host
void pendInterrupt(uint8_t kind)
{
  int_pending = kind;
}


// Reset procedure, both hard and soft. Page 22.
void esdiReset()
{
  //
  // Do initialization tasks here
  //

  // Make sure all handshaking flags are cleared
  setFlag(_BV(FLAG_CLEAR_ALL));
  delayMicroseconds(10);
  Serial.print("in clear. flags: ");
  Serial.println(portRead(REG_FLAGS), HEX);
  clearFlag(_BV(FLAG_CLEAR_ALL));
  clearFlag(_BV(FLAG_CMD_PROG)); // Clear any commands in progress
  
  transfer_state = TS_IDLE;

  // Generate reset complete interrupt
  startStatusBlock(1, DEV_CONTROLLER); // Page 61: load status block data
  loadStatusBlock();
  doISR(ISR_RESET_OK); // Success. Failure is 0xFA
  pendInterrupt(PEND_INT_RESET);
}


// Processes a received command block (page 24)
void processCmdBlock()
{
  uint16_t i;
  uint16_t cmd_no_opt = cmd_block[0] & CMD_NO_OPT_MASK;
  Serial.print("CMD: ");
  Serial.println(cmd_block[0], HEX);

  // After command, fill in the status block
  // then trigger a command complete interrupt

  switch (cmd_no_opt) {
    case 0x4001: // Read data (sector) page 41
      // TODO: Validate transfer count or trigger a command error
      // cmd_block[1] = number of RBAs to read
      // cmd_block[2] = low word RBA offset
      // cmd_block[3] = high word RBA offset
      current_rba = cmd_block[2] | cmd_block[3] << 16;
      rba_transfer_count = cmd_block[1];
      Serial.print("R");
//      Serial.print("Preparing to read sector ");
//      Serial.println(current_rba, DEC);
      status_max = 0; // No status data
      //for (i = 0; i < 512; i++) {
      //  transfer_buffer[i] = i & 0xFF;
      //}
      readDiskRBA(current_rba);
      since_dma_start = 0; // Benchmarking
      doISR(DEV_DRIVE | ISR_DATA_XFER_RDY);
      transfer_state = TS_READ;
      transfer_count = 512; // Our buffer is just one sector to make things easy
      transfer_index = 0;
      no_disk_op = false;
      
      //Serial.print("ReadData: ");
      //Serial.println(transfer_count, DEC);
      // Do not pend interrupt since we do not expect EOI for this
      return;

    case 0x4002: // Write data (sector) page 48
    case 0x4004: // Write with verify (page 49)
      current_rba = cmd_block[2] | cmd_block[3] << 16;
      rba_transfer_count = cmd_block[1];
      Serial.print("Preparing to write sector ");
      Serial.println(current_rba, DEC);
      status_max = 0; // No status data
      // TODO: Validate RBA?
      doISR(DEV_DRIVE | ISR_DATA_XFER_RDY);
      setFlag(_BV(FLAG_TREQ_SET));
      transfer_state = TS_WRITE;
      transfer_count = 512; // Our buffer is just one sector to make things easy
      transfer_index = 0;
      no_disk_op = false;
      //Serial.print("WriteData: ");
      //Serial.println(transfer_count, DEC);
      // Do not pend interrupt since we do not expect EOI for this
      return;

    case 0x4003: // Read Verify (page 42)
      Serial.println("Read verify.");
      doISR(0x01);
      prepDefaultSB();
      // cmd_block[1] = number of blocks requested
      // cmd_block[2], cmd_block[3] = RBA, low and high
      break;

    case 0x4005: // Seek (page 44)
      Serial.println("SEEK COMMAND");
      doISR(0x01); // Command complete for drive
      prepDefaultSB();
      break;

    case 0x0006: // Park head
      Serial.println("Park head");
      doISR(0x01);
      prepDefaultSB();
      break;

    case (DEV_CONTROLLER | 0x7):
    case 0x7: // Get command complete status
      Serial.println("CmdComplete Status");
      portWrite(REG_ISR, 0x01); // Manually trigger ISR. Retain and send existing status block
      break;

    case (DEV_CONTROLLER | 0x8):
    case 0x8: // Get device status
      Serial.println("Get Device Status");
      startStatusBlock(3, cmd_block[0]);
      status_block[1] = 0x0000;
      status_block[2] = (sb_dev_status << 8) | sb_dev_error; // TODO: error codes depend on drive/controller
      doISR(0x01);
      break;

    case 0x9: // Get Configuration (Drive) (page 37, 55)
      Serial.println("Get config, drive");
      // FIXME: Check bit 11 (cmd_block[0] & _BV(11)) for 0=physical or 1=pseudo
      startStatusBlock(6, cmd_block[0]);
      if (cmd_block[0] & _BV(11)) { // bit 11, 1=pseudo RBA
        Serial.println("Pseudo");
        status_block[1] = 0x0200;
        status_block[2] = (psu_rba_max + 1) & 0xFFFF; // Low word number of RBAs
        status_block[3] = (psu_rba_max + 1) >> 16; // High word number of RBAs
        status_block[4] = disk_size / 2048; // Number of cylinders
        status_block[5] = (0x20 << 8) | 0x3f; // 32 sectors per track, 64 tracks per cylinder
      } else {
        // We don't need to do this, but we're just using the BIOS's default CHS mapping
        // to calculate the number of cylinders, tracks, and heads.
        status_block[1] = 0x200; // ZD bit clear
        status_block[2] = disk_size & 0xFFFF; // Low word number of RBAs
        status_block[3] = disk_size >> 16; // High word number of RBAs
        status_block[4] = disk_size / 2048; // Number of cylinders
        status_block[5] = (0x20 << 8) | 0x3f; // 32 sectors per track, 64 tracks per cylinder
      }
      doISR(0x01);
      break;

    case (DEV_CONTROLLER  | 0x9): // Get Configuration (controller) (page 37, 56)
      Serial.println("Get config, controller");
      doISR(DEV_CONTROLLER  | 0x1); // Command complete for controller
      startStatusBlock(6, cmd_block[0]);
      status_block[1] = 0x0000; // Reserved
      status_block[2] = 0x0001; // Firmware revision code, low word
      status_block[3] = 0x3101; // buf_size1, revision code high byte, buffer size code (256 words)
      status_block[4] = 0x0000; // buf_size2
      status_block[5] = 0x0000; // Reserved
      break;

    case (DEV_CONTROLLER | 0xA): // Get POS information (page 39)
      Serial.println("Get POS info");
      doISR(DEV_CONTROLLER | 0x1);
      startStatusBlock(5, cmd_block[0]);
      i = portRead(REG_POS01);
      status_block[1] = (i >> 8) | (i << 8);
      i = portRead(REG_POS23);
      status_block[2] = (i >> 8) | (i << 8);
      i = portRead(REG_POS4);
      status_block[3] = (i << 8) | 0xFF;
      status_block[4] = 0xFFFF;
      break;

    //case 0x400B: // Translate RBA, seldom used, really only for low level format (page 47)

    case (DEV_CONTROLLER | 0x10): // Write attachment buffer (page 48)
      // cmd_block[1] = the block count, same for all data transfer commands
      status_max = 0; // No status block
      doISR(DEV_CONTROLLER | ISR_DATA_XFER_RDY);
      setFlag(_BV(FLAG_TREQ_SET)); // Tell host (initially) to send us data
      transfer_state = TS_WRITE;
      transfer_count = cmd_block[1] * 512;
      transfer_index = 0;
      no_disk_op = true; // Make sure we don't write this to the disk image
      rba_transfer_count = 1; // Just one
      // TODO: Validate transfer count or trigger a command error
      Serial.print("WriteAttachBuffer: ");
      Serial.println(transfer_count, DEC);
      // Do not pend interrupt since we do not expect EOI for this
      return;

    case (DEV_CONTROLLER | 0x11): // Read attachment buffer (page 41)
      status_max = 0; // No status block
      doISR(DEV_CONTROLLER | ISR_DATA_XFER_RDY);
      transfer_state = TS_READ;
      transfer_count = cmd_block[1] * 512;
      transfer_index = 0;
      no_disk_op = false; // Make sure we don't read this from the drive
      rba_transfer_count = 1; // We do not want to try to read the disk, just return the buffer.
      current_rba = 0;
      // TODO: Validate transfer count or trigger a command error
      Serial.print("ReadAttachBuffer: ");
      Serial.println(transfer_count, DEC);
      // Do not pend since we do not expect EOI for this
      return;

    case 0x0012: // Run diagnostic test (page 43)
      // Test number is in cmd_block[1]
      // TODO: perform a test, set a code, whatever
      doISR(0x01); // Command complete for drive.
      prepDefaultSB();
      break;

    case (DEV_CONTROLLER | 0x0012): // Run diagnostic test (page 43)
      // Test number is in cmd_block[1]
      // TODO: perform a test, set a code, whatever
      doISR(0x01); // Command complete for drive.
      prepDefaultSB();
      break;

    case 0x0014: // Get Diagnostic Status Block, drive 0 (page 37)
      // See page 58 and page 49
      doISR(0x01); // Command complete for drive. Page 25
      prepDefaultSB();
      status_block[3] = 0x0000; // por error code, test error code
      status_block[4] = 0x0000; // diagnostic command (probably from last Run Diagnostics command)
      status_block[5] = 0x0000; // Reserved
      status_block[6] = 0x0000; // Reserved
      break;

    case 0x0015: // Get Manufacturing Header (page 38)
      Serial.println("Preparing manufacturing header.");
      status_max = 0; // No status data
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
void loop() {
  uint16_t d, i;
  uint8_t cmd, t;
  // put your main code here, to run repeatedly:
  // Comment out the following two lines for debugging
  esdiReset();
  mainLoop();

  // FIXME: make it an interrupt?
  t = digitalReadFast(PIN_INT);
  if (t != oldint) {
    oldint = t;
    if (t == 1) {
      Serial.println("Interrupt asserted.");
    }
    if (t == 0) {
      Serial.println("Interrupt deasserted.");
    }
  }

  if (Serial.available() > 0) {
    cmd = Serial.read();
    if (cmd == 'F') {
      Serial.print("Enter data for flags: ");
      d = read8();
      portWrite(REG_FLAGS, d);
      Serial.println();
    }
    if (cmd == 'f') {
      d = portRead(REG_FLAGS);
      Serial.print("Flag reg: ");
      Serial.println(d, HEX);
    }
    if (cmd == 'a') {
      i = portRead(REG_ATN);
      Serial.print("ATN reg: ");
      Serial.println(i & 0xFF, HEX);
    }
    if (cmd == 'i') {
      Serial.print("Enter data for ISR: ");
      d = read8();
      portWrite(REG_ISR, d);
      Serial.println();
    }
    if (cmd == 'c') {
      i = portRead(REG_CIFR);
      Serial.print("CIFR reg: ");
      print16hex(i);
      Serial.println();
    }
    if (cmd == 'C') {
      Serial.println("CIFR test loop.");
      CIFRTestLoop();
    }
    if (cmd == 'S') {
      Serial.println("SIFR test loop.");
      SIFRTestLoop();
    }
    if (cmd == 'A') {
      Serial.println("ATN test loop.");
      ATNTestLoop();
    }
    if (cmd == 'I') {
      Serial.println("ISR test loop.");
      ISRTestLoop();
    }
    if (cmd == '1') {
      Serial.println("Teensy -> DREG -> host");
      DREGToHostTestLoop();
    }
    if (cmd == '2') {
      Serial.println("Teensy <- DREG <- host");
      DREGFromHostTestLoop();
    }
    if (cmd == 's') {
      Serial.print("Enter data for SIFR: ");
      d = read16();
      portWrite(REG_SIFR, d);
      Serial.println();
    }
    if (cmd == 'q') {
      Serial.println("Starting SD card test.");
      sdTest();
    }
    if (cmd == 'G') {
      Serial.println("Starting main loop.");
      esdiReset();
      mainLoop();
    }
  }
}

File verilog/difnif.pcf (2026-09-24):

### icetest

### Copyright (c) 2021 Eric Schlaepfer
### This work is licensed under CERN-OHL-S-2.0.

### Clock
set_io clk_10m      49

### Micro Channel bus
set_io chreset_l    52 # Probably not actually chreset_l!

set_io cd_ds16_l    73
set_io irq14_l      74
set_io cd_chrdy_l   75
set_io chreset      76
set_io sbhe_l       78
set_io s0_w_l       79
set_io s1_r_l       80
set_io cmd_l        81
set_io bus_a[3]     82
set_io bus_a[2]     83
set_io arb_o[3]     84
set_io arb_o[2]     85
set_io arb_o[1]     87
set_io arb_o[0]     88
set_io burst_o_l    90
set_io preempt_o_l  91
set_io bus_a[1]     93
set_io m_io_l       94
set_io bus_a[0]     95
set_io arb_gnt_l    96
set_io tc_l         97
set_io arb[3]       98
set_io arb[2]       99
set_io arb[1]       101
set_io arb[0]       102
set_io burst_l      104
set_io preempt_l    105
set_io cd_setup_l   106
set_io addr_sel_in_l 107
set_io bus_d[13]    110
set_io bus_d[11]    112
set_io bus_d[10]    113
set_io bus_d[7]     114
set_io bus_d[6]     115
set_io bus_d[5]     116
set_io bus_d[2]     117
set_io bus_d[0]     118
set_io bus_d[15]    119
set_io bus_d[14]    120
set_io bus_d[12]    121
set_io bus_d[9]     122
set_io bus_d[8]     124
set_io bus_d[4]     125
set_io bus_d[3]     128
set_io bus_d[1]     129
set_io data_dir     130

# Extended address lines
# 72-pin interface only
set_io bus_a[4]     39
set_io bus_a[5]     41
set_io bus_a[6]     42
set_io bus_a[7]     43
set_io bus_a[8]     44
set_io bus_a[9]     45
set_io bus_a[10]    47
set_io bus_a[11]    48
set_io bus_a[12]    55
set_io bus_a[13]    56
set_io bus_a[14]    60
set_io bus_a[15]    61

set_io fulladdr_l   62

# Card selected feedback, 72-pin only. Needs Rev P2: drives the input of the
# spare 74VHCT125 section (U12 pin 12, /OE grounded), push-pull to J1 B08.
# Pin 134 is unconnected on Rev P1.
set_io cd_sfdbk_l   134

### Teensy connections
# Data port (bidirectional)
set_io tn_d[0]      29
set_io tn_d[1]      28
set_io tn_d[2]      21
set_io tn_d[3]      23
set_io tn_d[4]      17
set_io tn_d[5]      18
set_io tn_d[6]      26
set_io tn_d[7]      25
set_io tn_d[8]      33
set_io tn_d[9]      34
set_io tn_d[10]     31
set_io tn_d[11]     32
set_io tn_d[12]     11
set_io tn_d[13]     16
set_io tn_d[14]     15
set_io tn_d[15]     12

# Address pins
set_io tn_addr[0]   24
set_io tn_addr[1]   20
set_io tn_addr[2]   22
set_io tn_addr[3]   19

# Control pins
set_io tn_rd        143
set_io tn_wr        10
set_io tn_int       144
set_io tn_clk       141

# Spares
set_io tn30         142

### LEDs
set_io led0         37
set_io led1         38

### SD card
set_io sd_clk       1
set_io sd_cmd       2
set_io sd_switch    3
set_io sd_d[1]      4
set_io sd_d[0]      7
set_io sd_d[3]      8
set_io sd_d[2]      9

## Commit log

2023-08-15 add data byte steering
2023-08-23 initial teensy port
2023-08-23 add teensy sketch and interface with test reg
2023-08-30 register access from MCA to Teensy works!
2023-09-04 add flag bits and interrupt
2023-09-23 Hook up interrupt output
2023-09-28 attach buffer cmds and read sector!
2023-09-29 fix interrupt behavior
2023-09-30 initial (broken) dma
    Read DMA sometimes works. Write DMA freezes the machine.
    [difnift.ino]
2023-10-03 fix la_dma_selected holding too long during write dma cycle
2023-10-04 DMA (non burst) working.
2023-10-05 add hard reset. code cleanup.
    [difnift.ino]
2023-10-17 Add 1C cmd variant. Fix write off-by-two error
    [difnift.ino]
2023-10-19 fix atn flag clock domain crossing issue
    [difnif.pcf, difnift.ino]
2023-10-20 speedup Teensy to FPGA interface
2023-10-20 Add synch clock line to Teensy interface
2023-11-10 Add PCB files
    [700CExtender.kicad_pcb, 700CExtender.kicad_sch, DifNif.kicad_pcb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]
2023-11-11 Added 72-pin form factor board
    [DifNif.kicad_pcb, DifNif.kicad_sch, DifNifBus.kicad_sch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]
2023-11-11 Add diode OR, add clock series R
    [DifNif.kicad_pcb, DifNif.kicad_sch, DifNifBus.kicad_sch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]
2023-11-28 fix rare dma glitch
2023-11-28 fabout form factor pcb
    [DifNif.kicad_pcb, DifNif.kicad_sch]
2023-12-02 Support 72-pin form factor
2026-01-27 Readme, docs, update license
    [2finglong.STL, df9f_carrier.STL, difnif_PS2_drive_sled.STL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]
2026-09-24 Add static board checker and 72-pin review findings
    [dba_esdi_72pin.csv]
2026-09-24 Add 72-pin bus-timing testbench; record simulation findings
2026-09-24 Fix write capture, 72-pin address decode; add -CD SFDBK output
    [difnif.pcf, difnif72_t.v]
2026-09-24 Add DMA arbitration and transfer tests; fix stale DMA request
    [difnif72_t.v]
2026-09-24 Rev P2 schematic: CHRESET fix, 74LVC8T245, -CD SFDBK, debug header
    [DifNif.kicad_sch, DifNifBus.kicad_sch]
2026-09-24 Rev P2: update PCB from schematic
    [DifNif.kicad_pcb]
2026-09-24 Rev P2 layout: route -CD SFDBK via J4 (in progress)
    [DifNif.kicad_pcb]
2026-09-24 Drive -CD SFDBK push-pull from U12 pin 12; ignore KiCad working files
    [DifNifBus.kicad_sch]
2026-09-24 Rev P2 layout: route -CD SFDBK push-pull via J4, reset fix
    [DifNif.kicad_pcb]
2026-09-24 Rev P2: 8.7 mm key slot between pins 2 and 3, narrow adjacent fingers
    [DifNif.kicad_pcb]
2026-09-24 Rev P2: update silkscreen revision
    [DifNif.kicad_pcb]
2026-09-24 Rev P2: credit line, refilled pours, fab files
    [DifNif.kicad_pcb]
2026-09-24 Rev P2 assembly: BOM, placement file, SMD footprint types
    [DifNif.kicad_pcb, DifNifFormFactor-RevP2-BOM.csv, DifNifFormFactor-RevP2-positions.csv]
2026-09-25 Relabel level-shifter symbol as 74LVC8T245; note Model 70 socket is unkeyed
    [DifNifBus.kicad_sch]
2026-09-25 Review: 55SX socket is keyed, Model 70 riser is not
2026-10-02 Start edge fingers 1.15 mm from the edge for the bevel, as PCBWay is fabricating them
    [DifNif.kicad_pcb]
2026-10-03 Makefile: BOARD=ps2 builds the 72-pin version with POS enabled
2026-10-03 README: describe the fork, both boards and current status

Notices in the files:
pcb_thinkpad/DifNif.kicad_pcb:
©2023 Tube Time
